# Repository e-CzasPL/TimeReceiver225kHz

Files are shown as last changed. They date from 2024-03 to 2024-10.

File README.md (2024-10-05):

# TimeReceiver225kHz
<html>
<body>
<H1>A simple receiver module for decoding a time frame from a 225kHz transmitter PCSK-225 in Solec Kujawski, Poland</h1>

<H2>Content</H2>
<h3>English</h3>
<ul>
  <li><a href="#en1">Changes</li>
  <li><a href="#en1">What's e-Czas</a></li>
  <li><a href="#en2">What's e-Czas Radio?</a></li>
  <li><a href="#en1">Flash programming guide</a></li>
</ul>
<h3>Polski</h3>
<ul>
<li><a href="#pl0">Zmiany</a></li>
<li><a href="#pl1">Co to jest e-Czas?</a></li>
<li><a href="#pl2">Co to jest e-Czas Radio?</a></li>  
<li><a href="#pl3">Instrukcja programowania procesora</a></li>
</ul>
<h2 id="en0">Changes</h2>
<ul>
  <li><b>2024-06-11:</b> Thanks to Damian Jabłoński, who found an error in the scheme. This caused the processor to operate unstablely. Resistor R2 20k (shown in the current schematic) should be added to fix the error.</li>
   <li><b>2024-06-12:</b> 
   The repository contains corrected versions of the project files in KiCAD. In the KiCAD/1.0/bom folder, you can find the interactive BOM in HTML. In the KiCAD/1.0/production folder, you can find production (Gerber) files for fixed PCB.
   </li>
      <li><b>2024-06-14:</b> The repository contains corrected versions firmware. It doesn't need the resistor R2 (20k). Currently is used internal pull-up resistor.
   </li>

</ul>

<h2 id="en1">What's e-Czas</h2>

<p>Providing the service of reliable and reliable distribution of official time signals valid in the territory of the Republic of Poland and signals of the Polish implementation of the international coordinated universal time UTC (PL), based on the state standard for time measurement units and frequency, with the status (guarantee) of official time and synchronization monitoring service.

<h2 id="en2">What's e-Czas Radio?</h2>

<p>The e-Czas Radio service is used to distribute coded official time signals in the territory of the Republic of Poland using long radio waves. End-user synchronization accuracy: &lt;0.01 s
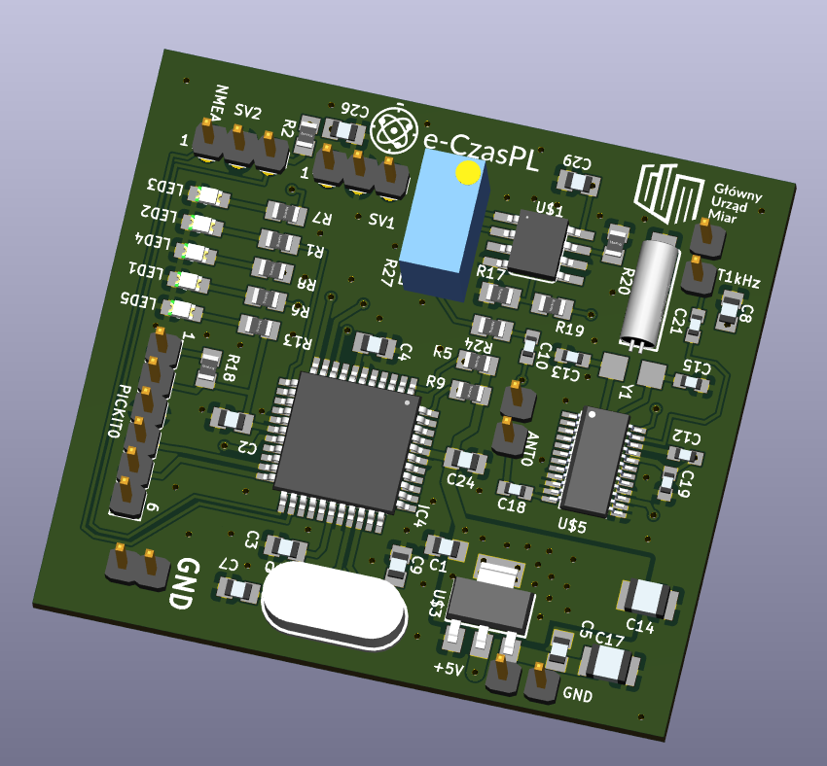
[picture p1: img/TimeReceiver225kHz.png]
Time Receiver 225kHz

<p>As part of the e-CzasPL project, a service was launched for emitting coded digital time signals on long waves, using the 225 kHz carrier wave of the First Polish Radio Program, from a transmitter located in Poland (a technique similar to the DCF77 (Germany), WWVB (USA), JJY (Japan) system, but based on signal phase modulation), which creates a generally available option to synchronize any time-measuring device with the official time in the Republic of Poland using cheap, energy-saving and simple receiving devices. This technique allows many time-measuring devices to be synchronized to the official time in the Republic of Poland with an accuracy of several or a dozen milliseconds. The system is an additional (redundant) source of time information for users located in Poland.
<p>The standard signals are generated using a stable frequency module based on highly stable rubidium frequency standards in the Radio Broadcasting Center (RCN) in Solec Kujawski. Using receiving devices located at the headquarters of the Central Office of Measures in Warsaw, employees of the Time and Frequency Laboratory remotely monitor changes in the frequency of the carrier wave, as well as monitor the accuracy of encoded time signals and compare them with the Official Time Scale in force in the Republic of Poland generated and maintained in the Central Office of Measures.

<p>The technique using digitally coded time signals involves emitted radio waves from RCN Solec Kujawski and the use of dedicated receivers by end users. You can download documentation related to the technical parameters of the transmitted time signal and a description of the process of making a simplified receiver of coded official time signals on the 225 kHz carrier wave of the First Polish Radio Program.
<br><br>
<ul>
<li>In the "/doc" folder, you will find documentation (in Polish) describing how to encode and receive a time frame. 
<li>In the "/Eagle" folder, you can find the design of the receiver in Autodesk Eagle format. 
<li>In the "/KiCAD" folder, you can find the design of the receiver in KiCAD format. 
<li>In the "/Firmware" folder, you can find firmware for the DSPIC33FJ128GP804 processor in HEX format. 

</ul>

<h3>Power</h3>
<p>The best solution is to use a 5V power supply, e.g. USB. Current consumption is approximately 100mA @ 5V.</p>

<h2 id="en3">Flash programming guide</h2>
<p>I use <a href="https://www.microchip.com/en-us/development-tool/PG164150" target=_blank>PICKIT5, which is not much more expensive than the previous ones and can program without a computer, in the "field." The instructions below describe installing the required software in a Windows 11 environment.
<ol>p
<li>Install <a href="https://www.microchip.com/en-us/tools-resources/develop/mplab-x-ide" target=_blank>MPLAB X IDE</a>
<li>When you install MPLAB and connect PICKIT5 to USB, sometimes the system doesn't recognize it properly. Then open "Device Manager" and check the "Ports (COM & LPT) section. It should look like this:<br><br>
In the "Universal Serial Bus devices"<br><br>If no drivers are installed, this will show<br>>
<br>In the "Microchip Tools"<br>
<br>If the last section does not exist, you must update the drivers on your device, which will appear in the "Universal Serial Bus devices" section.
<li>Without the correct driver, the system will show the error "Failed to get Device ID. Please ensure the target device is attached and try the operation again."
<li>Check the 3V3 power supply at the output of the LM1117 stabilizer
<li>Connect the PICKIT5 programmer to the connector on the board. (pins 1 to 5)
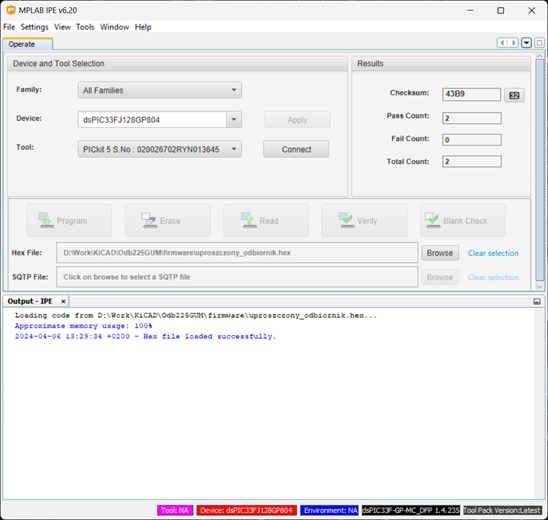
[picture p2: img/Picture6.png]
<li>Run MPLAB IPE - specify the path to the HEX file, processor type<br>
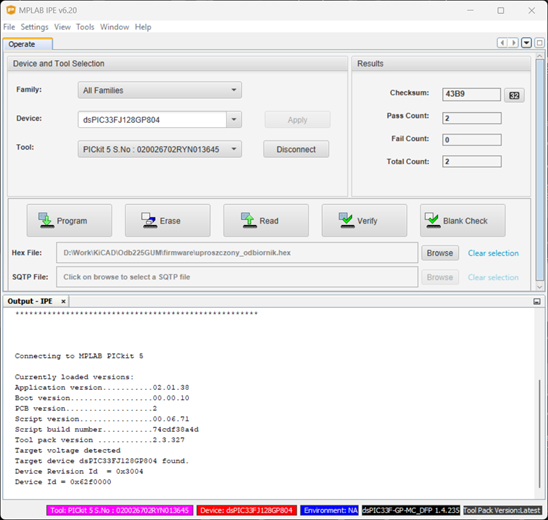
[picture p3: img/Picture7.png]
<li>Click "Connect", the board must be powered<br>
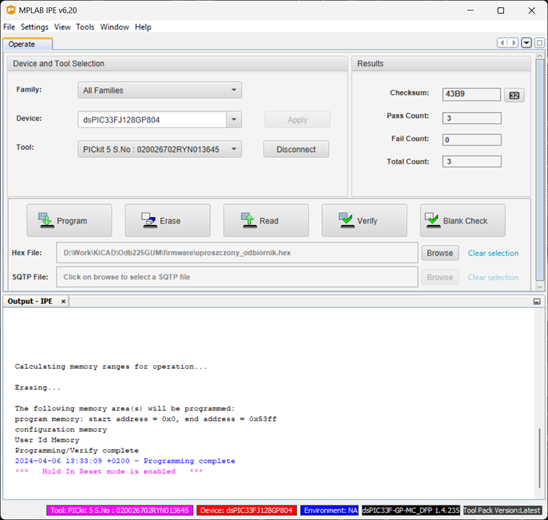
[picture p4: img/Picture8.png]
<li>Program CPU<br>
<li>Turn off the power, disconnect the programmer
</ol>

<h1>Prosty moduł odbiorczy do dekodowania ramek czasu z nadajnika PCSK-225 225kHz w Solcu Kujawskim</h1>

<h2 id="pl0">Zmiany</h2>
<ul>
  <li><b>2024-06-11:</b> Dziękuję Damianowi Jabłońskiemu, który znalazł błąd w schemacie i opracował poprawkę. Błąd skutkował niestabilną pracą procesora. Rozwiązaniem jest dolutowanie rezystora R2 między pinem 3 złącza SV2 a VDD rezystora 20k (R2). Poprawka naniesiona jest na aktualną wersję projektu w KiCAD</li>
   <li><b>2024-06-12:</b> Repozytorium zawiera poprawione pliki projektu. W folderze KiCAD/1.0/bom znajdziesz interaktywny BOM w HTML ułatwiający montaż, w foderze KiCAD/1.0/production są aktualne pliki produkcyjne (Gerber) poprawionego PCB - można je np. wysłać do produkcji (bez rozpakowania).
   </li>
      <li><b>2024-06-14:</b> Repozytorium zawiera poprawiony plik HEX z firmware.  Nie jest konieczne umieszczanie rezystora R2(20k). Obecnie używany jest wewnętrzny rezystor pull-up.
   </li>

</ul>

<h2 id="pl1">Co to jest e-Czas</h2>
Jest tu usługa dystrybucji wiarygodnej i niezawodnej sygnałów czasu urzędowego, obowiązującego na obszarze Rzeczypospolitej Polskiej i sygnałów polskiej realizacji międzynarodowego uniwersalnego czasu koordynowanego UTC(PL), generowanych w oparciu o państwowy wzorzec jednostek miar czasu i częstotliwości, posiadającego status (gwarancję) czasu urzędowego oraz usługi monitorowania synchronizacji.

<h2 id="pl2">Co to jest e-Czas Radio</h2>

<p>Główny Urząd Miar (GUM) uruchomił serwis emitowania kodowanych cyfrowych sygnałów czasu na falach długich, przy wykorzystaniu fali nośnej 225 kHz Programu Pierwszego Polskiego Radia, z nadajnika znajdującego się na terytorium Polski. Jest to technika podobna do systemu DCF77, ale oparta na modulacji fazy sygnału. 
W efekcie powstała ogólnodostępna możliwość zsynchronizowania z czasem urzędowym dowolnego urządzenia odmierzającego czas na obszarze Polski i dużej części Europy przy wykorzystaniu tanich, energooszczędnych i nieskomplikowanych urządzeń odbiorczych. Wykorzystanie tej techniki pozwala na zsynchronizowanie do czasu urzędowego na obszarze RP wielu urządzeń odmierzających czas z dokładnością kilku lub kilkunastu milisekund. System będzie dodatkowym (redundantnym) źródłem informacji o czasie dla użytkowników znajdujących się na terytorium Polski.

<p>Usługa Radia e-Czas służy do dystrybucji kodowanych oficjalnych sygnałów czasu na terytorium Rzeczypospolitej Polskiej za pomocą fal długich radiowych. Dokładność synchronizacji z użytkownikiem końcowym: <0,01 s
Odbiornik czasu 225kHz
<p>W ramach projektu e-CzasPL uruchomiono usługę emisji kodowanych cyfrowych sygnałów czasu na falach długich, wykorzystując falę nośną 225 kHz Pierwszego Programu Polskiego Radia, z nadajnika znajdującego się w Polsce (technika zbliżona do systemu DCF77 (Niemcy), WWVB (USA), JJY (Japonia), ale oparta na modulacji fazy sygnału),  co stwarza ogólnodostępną możliwość synchronizacji dowolnego urządzenia mierzącego czas z czasem urzędowym w Rzeczypospolitej Polskiej za pomocą tanich, energooszczędnych i prostych urządzeń odbiorczych. Technika ta pozwala na synchronizację wielu urządzeń do pomiaru czasu z czasem urzędowym w Rzeczypospolitej Polskiej z dokładnością do kilku lub kilkunastu milisekund. System jest dodatkowym (redundantnym) źródłem informacji o czasie dla użytkowników znajdujących się na terenie Polski.
<p>Sygnały standardowe generowane są w oparciu o moduł częstotliwości stabilnej oparty na wysoce stabilnych wzorcach częstotliwości rubidowych w Radiostacji Nadawczej (RCN) w Solcu Kujawskim. Pracownicy Laboratorium Czasu i Częstotliwości zdalnie monitorują zmiany częstotliwości częstotliwości fali nośnej, a także monitorują dokładność kodowanych sygnałów czasowych i porównują je z obowiązującą w Rzeczypospolitej Polskiej Oficjalną Skalą Czasu generowaną i utrzymywaną w Głównym Urzędzie Miar.

<p>Technika wykorzystująca cyfrowo kodowane sygnały czasu polega na emisji fal radiowych z RCN Solec Kujawski oraz wykorzystaniu dedykowanych odbiorników przez użytkowników końcowych. Można pobrać dokumentację związaną z parametrami technicznymi nadawanego sygnału czasu oraz opis procesu wykonania uproszczonego odbiornika kodowanych oficjalnych sygnałów czasu na fali nośnej 225kHz Pierwszego Programu Polskiego Radia (PCSK-225).
<br><br>
<ul>
<li>W folderze "/doc" znajdziesz dokumentację opisującą sposób kodowania i odbierania ram czasowych. 
<li>W folderze "/Eagle" znajduje się projekt odbiornika w formacie Autodesk Eagle. 
<li>W folderze "/KiCAD" znajduje się projekt odbiornika w formacie KiCAD. 
<li>W folderze "/Firmware" można znaleźć oprogramowanie układowe dla DSPIC33FJ128GP804 procesora w formacie HEX. 

</ul>
<h3>Zasilanie</h3>
<p>Najlepszym rozwiązaniem jest użycie zasilania 5V np. USB. Pobór prądu wynosi ok 100mA przy 5V.</p>

<h2 id="pl3">Instrukcja programowania procesora</h2>
<p>Ja używam <a href="https://www.microchip.com/en-us/development-tool/PG164150" target=_blank>PICKIT5, niewiele droższy od poprzednich a mający dodatkowo możliwość programowania bez komputera, w "polu". Poniżej opisuje instalację wymaganego oprogramowania w środowisku Windows 11.
<ol>
<li>Zainstaluj <a href="https://www.microchip.com/en-us/tools-resources/develop/mplab-x-ide" target=_blank>MPLAB X IDE</a>
<li>Po zainstalowaniu MPLAB i podłaczeniu PICKIT5 do USB czasami system nie rozpoznaje go prawidłowo. Wtedy otwórz "Device Manager" i sprawdź sekcję "Ports (COM & LPT). Powinna wyglądać tak:<br><br>
W sekcji "Universal Serial Bus devices"<br><br>Jeżeli nie są zainstalowane sterowniki, pokaże się to<br>>
<br>W sekcji "Microchip Tools"<br>
<br>Jeżeli ostatnia sekcja nie istnieje należy zaktualizować sterowniki w urządzeniu które pojawi się w sekcji "Universal Serial Bus devices".
<li>Bez prawidłowego sterownika, system pokaże błąd "Failed to get Device ID. Please make sure the target device is attached and try the operation again."
<li> sprawdzić zasilanie 3V3 na wyjściu stabilizatora LM1117
<li>Podłączyć programator PICKIT5 do złącza na płytce. (piny od 1 do 5)
<li>Uruchomić program MPLAB IPE - podać ścieżgę do pliku HEX, typ procesora<br>
<li>Kliknąć "Connect", płytka musi być zasilana<br>
<li>Zaprogramować procesor<br>
<li>Wyłączyć zasilanie, odłączyć programator
</ol>

<h2>Projekty połączone</h2>
<ol>
<li><a href="https://github.com/J-K-Kowalski/PCSK225-Antenna" target="_blank">Antena aktywna na tranzystorze FET</a></li>
<li><a href="https://github.com/J-K-Kowalski/PCSK225_RECV_USB" target="_blank">Odbiornik z interfejsem USB</a></li>
<li><a href="https://github.com/sp5wwp/e-Czas" target="_blank">SP5WWP - Dekoder e-Czas</a></li>
<li><a href="https://github.com/sp6hfe/e-CzasPL" target="_blank">e-CzasPL Radio reference C++ data decoder by SP6HFE</a></li>
</ol>

<p>Jurek K. Kowalski
<p>
<table border=0 cellpadding=0 cellspacing=0 width="100%"><tr>
<td align=left>
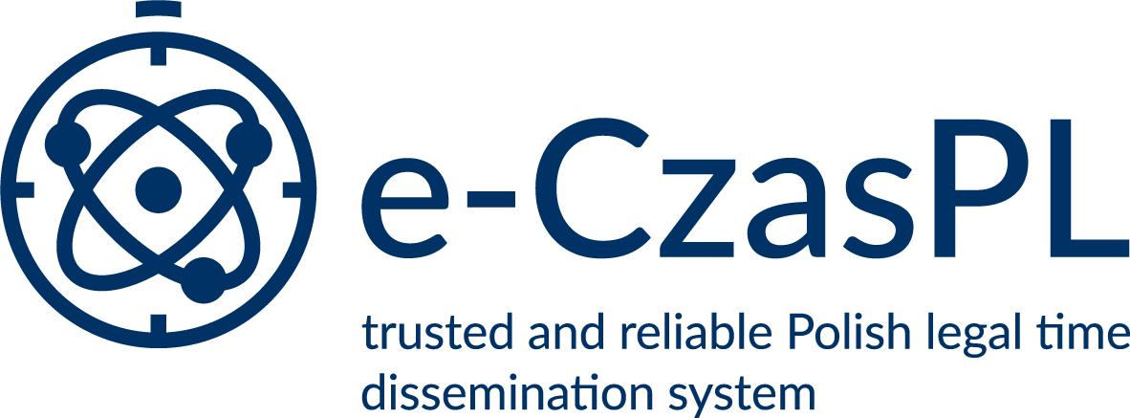
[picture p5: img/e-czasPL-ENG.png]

</td>
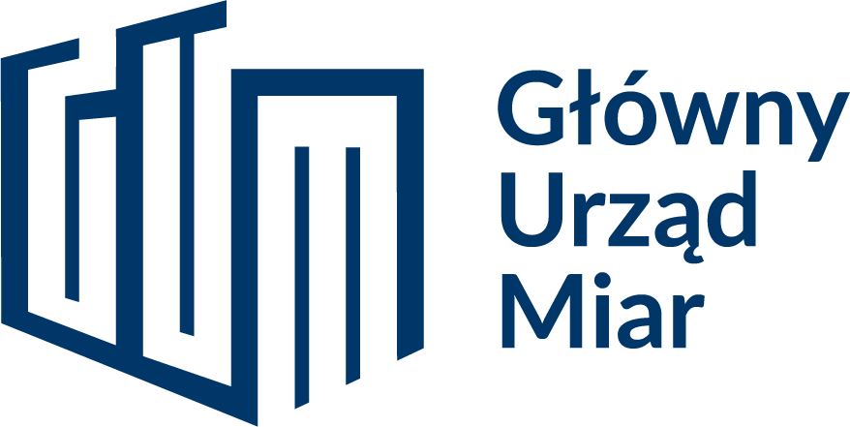
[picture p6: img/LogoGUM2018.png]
<td align=right>
</td>
</tr>
</table>
</body>
</html>

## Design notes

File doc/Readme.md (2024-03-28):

Distribution of Polish official time on long radio waves, using the 225 kHz carrier wave of the First Polish Radio Program - frame structure, transmitted data and their purpose.

Wersja polska
1. e-CzasPL-Opis-projektu-przykladowego-modulu-odbiorczego-e-Czas-Radio.pdf - dokumentacja do prostego odbiornika sygnałów czasu z nadajnika PCSK-225
2. e-CzasPL-Opis-ramki-czasu-e-Czas-Radio.pdf - opis ramki czasu w nadajniki PCSK-225

English version
1. Simple Time Receiver for PCSK-225.pdf - documentation of Simple Time Receiver.
2. PCSK-225 - Distribution of official time on long waves.pdf - description of time frame for PCSK-225 sender.

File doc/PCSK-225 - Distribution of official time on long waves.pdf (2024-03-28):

Distribution of official time Frame structure, transmitted data, and purpose

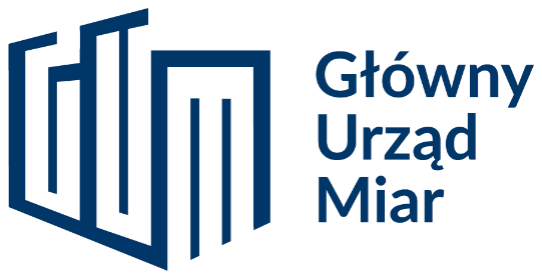
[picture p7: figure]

Distribution of official time on long waves, using.

## the 225 kHz carrier wave of the First Polish Radio Program

## frame structure, transmitted data, and its purpose

v. 1.0

Frame structure, transmitted data, and purpose

## Contents

Frame structure, transmitted data, and purpose

### 1. Diagram of the system:

The system's transmission is organized in time slots of 3 seconds. Messages are sent at a bit rate of 50 bps. In each time slot, the transmission starts at the beginning of the second. After transmitting each command, the system turns off the carrier phase modulation for the next full second. The traffic generated by the Radio Broadcasting Center (RCN) takes place in 20 time slots (from 0 to 19). They constitute a frame transported for 1 minute (minute frame).

Slot number | Elapsed time since the beginning of the broadcast [s] | Destiny
0 | 0 | Time Message 0
1 | 3 | Message 1
2 | 6 | Message 2
3 | 9 | Message 3
⋮ | ⋮ | ⋮
18 | 54 | Message 18
19 | 57 | Message 19

Fig. 1 Minute frame of the system.

Frame structure, transmitted data, and purpose

### 2. Structure of the official time frame:

A time frame consists of 12 bytes, i.e., 96 bits sent at a bit rate of 50 bits/s. This means that it takes 1.92 seconds to send a full-time frame.

BYTE
NO.

1

### 16 b → SYNCHRONIZATION STRING

2

3 8 b → TIMEFRAME START MARKER

4

### 3 b → TIME OF ENTRY TO RECEIVER

### 30 b → OFFICIAL TIME

5

6

7

8

### 2 b → LOCAL TIME

### 1 b → LEAP SECOND PREVIEW

### 1 b → LEAP SECOND SIGN

### 1 b → CHANGING LOCAL TIME

### 2 b → LONG-WAVE TRANSMITTER STATUS

9

10 24 b → REED-SOLOMON CORRECTION CODES

11

12 8 b → CRC-8 CHECKSUM

Fig. 2 Block structure of a time message.

Frame structure, transmitted data, and purpose

In addition, 2 B (0x680C – 0b0110 0b1000 0b0000 0b1100) are transmitted before each frame, which is the start sequence. They are not part of the time message.
The following is the bitwise frame format:

Fig. 3 Bit structure of a time message.
Purpose of individual bits:
- 0x55H | - constant synchronization pattern;
- 0x60H | - a permanent template signaling the beginning of the official time frame distributed as part of "e-CzasPL";
- 0x5H (0b101) - bits specifying the moment of entering the sent time into the
| receiver registers – delayed by 0.5 s (25b × 0.02 s = 0.50 s) about the moment of starting to transmit the frame;
- S0 ÷ S29 | - bits indicating the number of three-second periods counted from 1 January 2000 (3 × (S0 ÷ S29) = number of seconds counted from 1 January 2000;
- TZ0 ÷ TZ1 | - bits specifying the local time; to calculate the local time, add to the time received from the time frame the appropriate offset determined by bits TZ0 and TZ1 (according to the table below);
TZ0 | TZ1 | Local Time
0 | 0 | 0
1 | 0 | +1 hour
0 | 1 | +2 hours
1 | 1 | +3 hours
- LS | - bit indicating that a leap second announcement/no announcement is being broadcast: 0 – no leap second announcement, 1 – announcement of the introduction of a leap second; A leap second can be introduced at the beginning of the quarter: Variant I – 1 January or 1 July, Variant II – 1 April or 1 October
0 | 1 | 0 | 1 | 0 | 1 | 0 | 1 | 0 | 1 | 0 | 1 | 0 | 1 | 0 | 1
0 | 1 | 1 | 0 | 0 | 0 | 0 | 0 | 1 | 0 | 1 | S0 | S1 | S2 | S3 | S4
S5 | S6 | S7 | S8 | S9 | S10 | S11 | S12 | S13 | S14 | S15 | S16 | S17 | S18 | S19 | S20
S21 | S22 | S23 | S24 | S25 | S26 | S27 | S28 | S29 | TZ0 | TZ1 | LS | LSS | TZC | SK0 | SK1
Reed-Solomon ECC byte 0 | Reed-Solomon ECC byte 1
Reed-Solomon ECC byte 2 | CRC-8

Frame structure, transmitted data, and purpose

at 0:00 UTC; the leap second announcement should be broadcast in the period from a few days to a maximum of 1 week before the planned moment of introduction of the leap second;
- LSS | - the bit specifying the leap second sign:
| 0 – adding a second,
| 1 – subtract a second;
- TZC | - a bit informing that following Sunday at 1:00 UTC, there will be a
| change of local time to summer or winter/ordinary time. By default,
| daylight saving time changes occur on the last Sunday in March
| (Daylight Saving Time) and the last Sunday in October (Daylight
| Saving Time/Daylight Saving Time); the announcement of the
| upcoming time change should be broadcast up to a few days in
| advance (up to a maximum of 6 days) before the planned local
| time change;
- SK0 ÷ SK1 | - bits determining the state of the transmitter in Solec Kujawski
| according to the table below:
SK0 | SK1 | Condition of the transmitter PCSK-225 in Solec Kujawski
0 | 0 | Normal Operation
1 | 0 | Planned shutdown for one day
0 | 1 | Planned shutdown for a week
1 | 1 | Planned shutdown for more than a week

At the end of the time frame, 3 Reed-Solomon correction bytes are sent to allow correction of up to 24 bits of the frame. Bits to be corrected

### 3. Reed-Solomon Correction Coding:

The implemented Reed-Solomon algorithm can cover 36 bits. The correction covers bits S0 ÷ SK0 (marked in green in Fig. 1).

NOTE
The last bit of the SK1 usage data is not corrected (see Fig. 1). NOTE

The correction block consists of 24 redundant bits (bytes 9 ÷ 11).

### 4. Checksum and scrambling:

The last free byte is assigned to the CRC-8 checksum.

Frame structure, transmitted data, and purpose

NOTE
In the previous version of the time frame, 4 bytes of the R-S correction algorithm were predicted. (change after 04.09).

NOTE

The checksum is calculated from whole bytes 4 ÷ 8 (bits 25 ÷ 64) After scrambling, in the scramble process, the data is XOR with the string 0x0A47554D2B, which in the ASCII code corresponds to \NGUM+. Descrambling is accomplished by repeating this operation.

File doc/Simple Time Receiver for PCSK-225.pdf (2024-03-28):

Distribution of official time Description of an example receiver module

## Str. 1


## Distribution of official time on long waves, using the 225 kHz carrier wave of the First Polish Radio Program

## Description of the design of an exemplary receiver module for encrypted official time signals

v. 1.0

Description of an example receiver module

### 1 Table of contents

Description of an example receiver module

The Central Office of Measures (GUM) has launched a service for broadcasting encoded digital time signals on long waves, using the 225 kHz carrier wave of the First Polish Radio Program, from a transmitter located in the territory of Polish. It is a technique similar to the DCF77 system but based on signal phase modulation. As a result, it is possible to synchronize timekeeping devices in Poland and a large part of Europe with the official time using cheap, energy-efficient, and uncomplicated receiving devices. This technique makes it possible to synchronize many timekeeping devices with an accuracy of a few or several milliseconds to the official time in the territory of the Republic of Poland. The system will be an additional (redundant) source of time information for users located in Polish.

Using digitally coded time signals involves adding an appropriate device (modulator) to the infrastructure for emitting radio waves at RCN Solec Kujawski (PCSK-225) and implementing receivers. The receiver performs its tasks automatically (i.e., determines the official time based on the emitted time signals) after correctly receiving the received signal.

2 Technical requirements of the receiver, time signal parameters.

The receiver will be adapted to receive signals with the following characteristics:

1) frequency with a nominal value of 225 kHz, transmitted from the transmitter of the Radio Broadcasting Centre (PCSK-225) in Solec Kujawski, with amplitude modulation of the acoustic radio signal and a dynamic carrier wave level control system;
2) dynamically variable carrier wave level (in the range from 0 dB to approx. -6.4 dB relative to the maximum carrier wave level) depending on the depth of acoustic signal modulation (AM modulation) and the set operating mode;
3) possible periodic shutdown of the 225 kHz long-wave transmitter for the duration of inspections (on average once a year for approx. 20 hours) and maintenance (on average once every five years for approx. two weeks) and short-term interruptions in signal emission (typically less than 2 hours) for other reasons;
4) implemented PSK (Phase Shift Keying) modulation of the NRZ (Non-Return-To-Zero) type, binary signal with smooth linear phase changes of the carrier wave – with the possibility of changing (within a fixed limited range) selected coding parameters: the value of the depth of the (additional) phase shift of the carrier wave when transitioning to a new state (01 or 10), the time it takes to complete the transition to a new state (01 or 10), transmission speed;
5) possibility of periodic coexistence of additional frames with dynamically changed transmission parameters, length and content of the message – PSK modulation type NRZ – possibility of changed transmission speed, depth of (additional) phase shift of the carrier wave, time of transition to the new state, change of error correction code, frame length;
6) start of transmitting a group of frames: at every full minute and subsequent frames (start of sending) at intervals of 3 s, possible deliberate short-term interruptions in the

Description of an example receiver module

transmission of frames constituting multiples of the interval of 3 s;
7) no collision of frames transmitted for the needs of different systems (broadcasting schedules may overlap in time but do not coincide);
8) the transmission of each frame takes less than 3 seconds;
9) during the transition to the new state, the maximum deviation of the carrier wave frequency does not exceed ± 100 Hz;
10) adopted basic modulation format of encoded official time signals: PSK modulation type NRZ, transmission speed 50 bit/s, depth of (additional) phase shift of the carrier wave
- 36° ± 3.6° (10 % of the carrier wave period), frame length – 14 bytes, synchronization bytes, some transmission parameters may be slightly modified over time, e.g. the depth of the (additional) phase shift of the carrier wave, or the time of the transition to a new state (01 or 10);
11) the level (surface wave field strength) of the received 225 kHz signal from the longwave transmitter in the PCSK-225 in Solec Kujawski in most of the Polish region is estimated to be above 78 dB (μV/m) – there are areas where the signal level decreases locally to the level of about 70 dB (μV/m).

### 3 Receiver concept

The receiver can be divided into two functional blocks;
- Frontend RF - Radio Frequency Receiver
- DSP demodulator

The RF front end is based on the SI4735 integrated circuit, whose block diagram is shown in Figure 1.

Description of an example receiver module

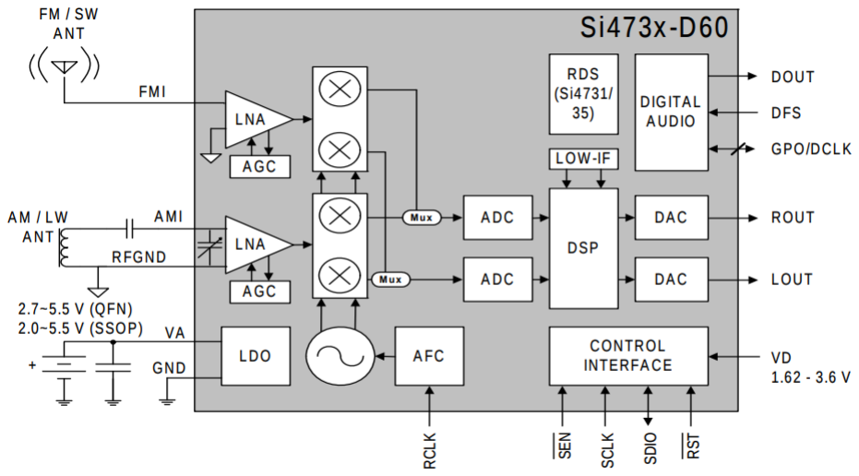
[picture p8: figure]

Figure 1. The RF frontend of the sample receiver module.

The device allows to receive long waves in the range of 153-279 kHz; thanks to the use of a DSP processor, it is possible to use the device in a non-standard way and use it as an SSB receiver (in this case, USB) working with BFO at a frequency of 224 kHz, which results in the reproduction of the transmitter's carrier wave output transferred to the acoustic band - in this case 1 kHz. In addition, the system provides automatic gain adjustment. The frontend layout is controlled by a frequency of 32.768 kHz obtained from a quartz generator.

The signal received this way is sent for further processing in the dsPIC33 signal processor. After initial filtering through a bandpass filter with a width of 200 Hz. Demodulator concept

During processing, the information from the PSK modulation signal is recovered in the DSP, and then, after passing through the packer, the frame classification takes place. When a keyword is detected, 0x60 subsequent bytes are written to the buffer, and R-S correction is performed. Then, the correctness of the received data is verified (the so-called "sanity checks")
- whether there has been a "time shift" or a "jump into the future" more significant than it would result from predictions based on the observation of the local RTC.

Measurement of time intervals between successive received frames will allow determining the frequency difference and carrying out systematic correction of the time scale created in the receiver.

After verifying the received data, the processor controls the 1PPS generator.

Description of an example receiver module

### 4 DSP Block Description

The DSP block is based on the dsPIC33FJ128GP804 processor. The processor was chosen due to design requirements (according to the order, the platform should be expandable in the future). The signal demodulation process takes about 10% of the processor's time, leaving a large reserve of computing power for future applications.

The processor's analog-to-digital converter input is supplied with an audio signal from the tuner's output. This type of solution allows you to separate the radio part from the digital part. In very difficult reception conditions (e.g., on deep-sea vessels), a professional radio communication receiver can also be used, and the audio signal can be delivered directly to the DSP.

The process of demodulating time frames takes several steps. After filtering the signal through a bandpass filter with a center frequency of 1 kHz and a bandwidth of 200 Hz, the signal is fed to a software-implemented Costas loop, which allows for the detection of changes in the signal's phase. The data stream is then passed to the bit-slicer, and the resulting bitstream feeds the packetizer, which parses the synchronization bits and the keyword.

When a data frame is received, correction codes are calculated, and frame consistency tests are performed.

In addition, the DSP will act as the RTC clock.

### 5 Data Frame Description

The following frame applies to the system.

### 5.1 Frame format

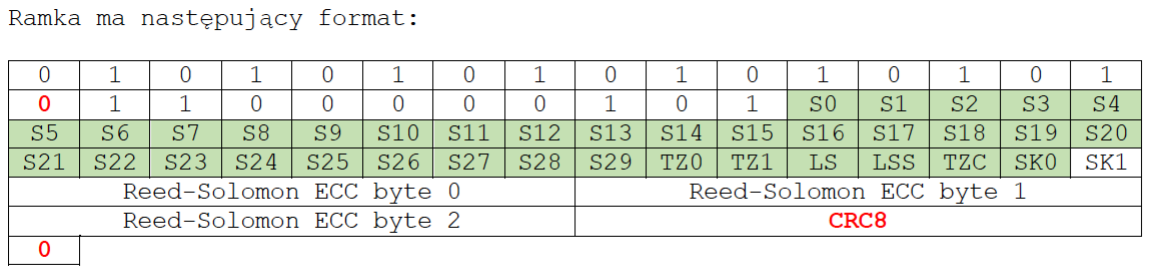
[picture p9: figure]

Table 1. The format of the official time frame.

It consists of 12 bytes, i.e., 96 bits sent at a bit rate of 50bit/s. This means that it takes 1.92s to send a total time frame. Frames are sent by the transmitter in Solec Kujawski in time slots

Description of an example receiver module

every 3 seconds. This will give the receiver ample time to demodulate and decode the sent frame. After two synchronization bytes (55H), the 60H beginning marker is sent, which differs by 7 bits from the marker used by Enea's system to control lighting. In this way, both systems will not interfere with each other (Enea's receivers, after detecting another tag, ignore the entire frame. Then three "1-0-1" (5H) bits are sent, of which bit 0 specifies the 'conventional' moment of entering the sent time into the receiver registers – delayed by 0.5s (25 bits x 0.02s = 0.50s) about the moment of starting to transmit the frame. S0 ÷ S29 Bits (30 bits) specifying the number of three-second seconds counted from 1 January 2000, i.e. 3 x (S0 ÷ S29) = number of seconds counted from 1 January 2000.

TZ0 TZ1 The bits specifying the local time are shown in the table below:

TZ0 | TZ1 | Local Time
0 | 0 | 0
1 | 0 | +1 hour
0 | 1 | +2 hours
1 | 1 | +3 hours

Table 2. Time bits.

### 5.2 Correction Codes

At the end of the time frame, 3 Reed-Solomon correction bytes are sent to allow correction of up to 24 bits of the frame.

The frame implements R-S encoding in the version:
4b - size of the codeword,
3b - correction strength.

What gives:
Data block: 9 words = > 36 bits,
Correction block: 6 words = > 24 bits.
The bits (S0 ÷ SK0) <= 36 bits are corrected - marked in the table. The last bit of SK1 usage data has not been corrected.
The last free byte is assigned to the CRC-8 checksum.

### 5.3 Scrambling

The usage data is XOR with the binary string 0A 47 55 4D 2B which corresponds to: "\NGUM+"

### 5.4 NMEA RMC Frame Format

The receiver of the e-CzasPL system is designed to provide information about the official time.

Description of an example receiver module

The NMEA protocol was used to facilitate the transition from GNSS to e-CzasPL, which simulates the behavior of a GNSS receiver. The RMC (Recommended Minimum Specific GNSS Data) sentence was used for time synchronization. For obvious reasons, the receiver does not know its geographical location. The static coordinates of the Time and Frequency Laboratory of the Central Office of Measures (52.24183 N, 21.00084 E) are transmitted in the frame to maintain compatibility with GNSS receivers.

An example of the GPRMC sentence is presented below:

$GPRMC,120000,A,5214.5098,N,02100.0504,E,0.00,000.021123,,E,A*CCCC

NAME | EXAMPLE | DESCRIPTION
Operative part ID | $GPRMC | NMEA Heading of RMC Operative Part
UTC | 120000 | hhmmss
Status | A | A – valid data, V – invalid data
latitude | 5214.5098 | ddmm.mmmm – GUM laboratory position
N/S | N | N – north latitude, S – south latitude
longitude | 02100.0504 | dddmm.mmmm - GUM laboratory item
E/W | E | E – east longitude, W – west longitude
velocity | 0.00 | Speed in knots – in this case, static position
course | 000.0 | Course in degrees - in this case, a static position
date | 021123 | ddmmyy
Magnetic deflection | | In this case, the static position
E/W | E | Direction of deviation mag. - Static position
Mode | A | A = Autonomous
checksum | *cccc
<CR><LF> | | End marker of the sentence
Table 3. An example of a GPRMC sentence.

The beginning of the NMEA sentence (the $ sign) is sent at the start of the second place in the sentence.

It is possible to modify the receiver firmware so that any geographical position can be entered during the receiver configuration.

5.5 5.5 DSP Firmware

The receiver software was written in C (central part) and Assembler (part of the demodulator) and was compiled with MPLAB XC16 PRO compiler version 2.10 on the Linux platform.

This documentation is accompanied by a HEX file that is ready to be uploaded to the DSP. One of the programmers must upload the software to the processor: PICKIT3, PICKIT4, PICKIT5, ICD-3, or ICD-4. The software can be uploaded to a microcontroller soldered to the PCB using the PICKIT connector.

Description of an example receiver module

### 6 Simple e-CzasPL Time Receiver

The e-CzasPL system's simple receiver has been designed to be built with a minimal set of tools. Manual assembly is possible, and only basic knowledge of working with SMD components is required. A properly built circuit does not require tuning or configuration. The device works immediately after connecting the power supply and is ready to receive the time signal.

The e-CzasPL signal receiver has been designed as an independent module that can be used as an official time standard on your devices. An exemplary receiver design can be used for one's needs in projects where information about the time related to the official time in force in the territory of the Republic of Poland is used.

The receiver provides time data in the form of NMEA RMC sentences, a 1 PPS signal, and a raw, unprocessed data frame for processing in an external system.

The receiver has a built-in RTC clock, which is designed to keep time for 24 hours from the last correctly received frame. After 24 hours, the "FIX" signal about time synchronization is extinguished. The system will still provide both time information (NMEA RMC sentence) and a 1PPS signal, but there is no guarantee that the required compliance with the official time will be maintained.

### 6.1 SV1 Diagnostic Connector

Similar to the basic version of the receiver, the SV1 connector has a UART port for the microcontroller operating at CMOS 3.3V levels—transmission parameters 115200 bps 8N1. Diagnostic information, including raw hexadecimal frames, is sent to the connector.

### 6.2 NMEA connector

Similarly to the basic version of the receiver, the SV2 connector is exposed to NMEA-compatible data carrying time information. The NMEA format was chosen for compatibility with GNSS-compatible devices. For a description of the NMEA frame, see Section 5.4. The connector operates at 3.3V CMOS levels

### 6.3 Antenna Connector

The antenna connector of the simplified receiver should be supplied with an RF signal from a ferrite antenna or an external antenna. The input circuit of the RF frontend is very tolerant and resistant to impedance mismatch.

Description of an example receiver module

### 6.4 Signaling the Operating Status of the Receiver

On the PCB of the Simple Receiver, 5 SMD LEDs indicate the receiver's operating status.
- LED1 – lit after correct receipt of the data frame, recalculated correction codes, and confirmed data correctness. The rising edge informs about the start of the second (transmitted in the data frame),
- LED2 – DCD – signaling of recognition of the beginning of the data frame (after the keyword is detected) – remains lit until the end of the frame transmission,
- LED3 – Informs about receiving the correct time and entering it into the RTC, if it is not possible to update the RTC from the radio transmission, the LED is turned off after 24 hours,
- LED4 – 1PPS 1PPS signal synchronized with the received time signal,
- LED5 – signaling the presence of a power supply to the system.

Remark! The 1PPS signal is valid (according to the official time) only when LED3 is lit.

7 7 Simplified Receiver Executive Documentation

The system was designed using Autodesk Eagle software. Schematic, mosaic, and GERBER files for PCB circuits are attached to this documentation. The circuit should be assembled, paying attention to the arrangement of electronic components, the integrated circuits' orientation, and the LEDs' polarity. The PCB is designed to facilitate the manual assembly of components.

It is not necessary to use a stencil to apply the solder paste. With some practice, installation can be done with tweezers and a classic soldering iron. A microscope or magnifying glass can be very helpful.

The time receiver has been designed so people without DSP programming or digital signal processing techniques can assemble and run it.

Figure 11 shows the schematic diagram of the time receiver.

Description of an example receiver module

7.1 7.1 Schematic diagram of the Time Receiver

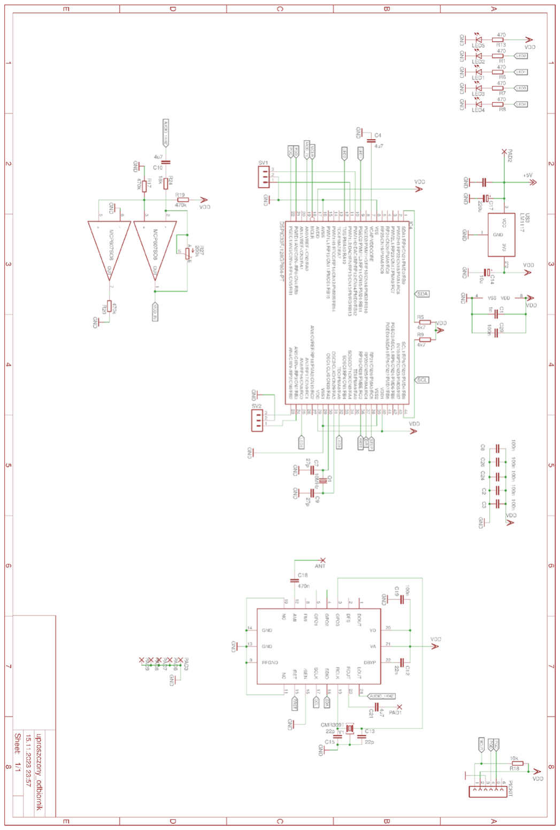
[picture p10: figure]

Figure 2. Schematic diagram of a time receiver.

Description of an example receiver module

### 7.2 Time Receiver PCB – Components Page

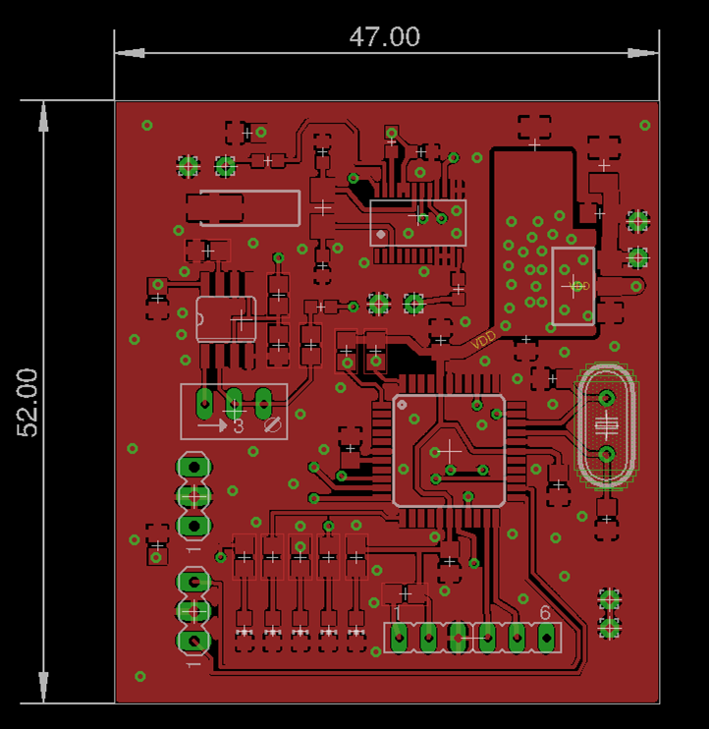
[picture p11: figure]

Figure 3. Time Receiver PCB – Components Page.

Description of an example receiver module

### 7.3 Time Receiver PCB – Print Side

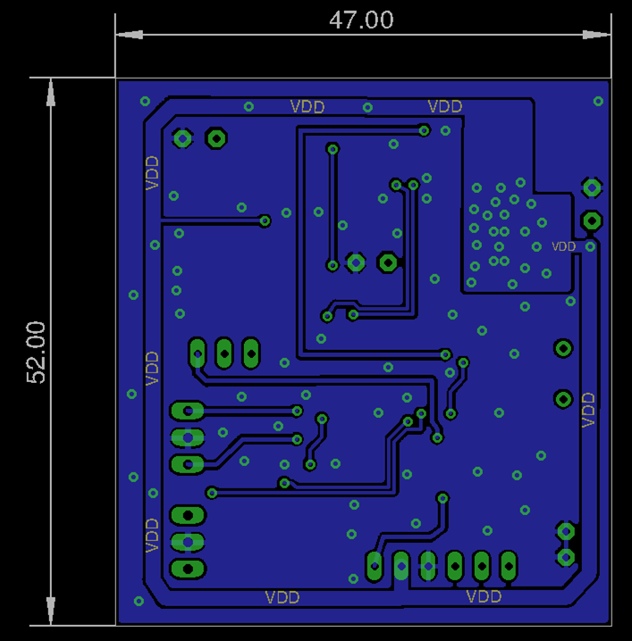
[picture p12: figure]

Figure 4. Simplified Receiver PCB – Print Side.

### 7.4 Time Receiver Bill of Materials (BOM)

Element | value | Device | Case
C1 | 1n | C-EUC0805K | C0805K
C2 | 100N | C-EUC0805K | C0805K
C3 | 100N | C-EUC0805K | C0805K
C4 | 4u7 | C-EUC0805K | C0805K
C5 | 100N | C-EUC0805K | C0805K
C7 | 27p | C-EUC0805K | C0805K
C8 | 100N | C-EUC0805K | C0805K

Description of an example receiver module

C9 | 27p | C-EUC0805K | C0805K
C10 | 4u7 | C-EUC0603K | C0603K
C12 | 22n | C-EUC0603K | C0603K
C13 | 22p | C-EUC0603K | C0603K
C14 | 10u | CPOL-EUSMCB | SMC_B
C15 | 22p | C-EUC0603K | C0603K
C17 | 220u | CPOL-EUSMCB | SMC_B
C18 | 470N | C-EUC0603K | C0603K
C19 | 100N | C-EUC0603K | C0603K
C21 | 4u7 | C-EUC0603K | C0603K
C24 | 100N | C-EUC0805K | C0805K
C26 | 100N | C-EUC0805K | C0805K
C29 | 100N | C-EUC0805K | C0805K
IC4 | DSPIC33FJ128GP804-PT | DSPIC33FJ128M | C804-PT TQFP44
LED1 | LED | LEDCHIP-LED0 | 805 CHIP-LED0805
LED2 | LED | LEDCHIP-LED0 | synchronize any timekeeping device in Polish and a large part of Europe with the official time using cheap, energy-efficient,
LED3 | LED | LEDCHIP-LED0 | 805 CHIP-LED0805
LED4 | LED | LEDCHIP-LED0 | 805 CHIP-LED0805
LED5 | LED | LEDCHIP-LED0 | synchronize any timekeeping device in Polish and a large part of Europe with the official time using cheap, energy-efficient,
PICKIT | pin connector 2.54x6 | FE06-1 | FE06
Q1 | Quartz 10MHz | CRYSTALHC49U | HC49U-V
R1 | 470 | R-EU_R0805 | R0805
R5 | 4k7 | R-EU_R0805 | R0805
R6 | 470 | R-EU_R0805 | R0805
R7 | 470 | R-EU_R0805 | R0805
R8 | 470 | R-EU_R0805 | R0805
R9 | 4k7 | R-EU_R0805 | R0805
R13 | 470 | R-EU_R0805 | R0805
R17 | 470k | R-EU_M0805 | M0805
R18 | 10k | R-EU_R0805 | R0805

Description of an example receiver module

R19 | 470k | R-EU_M0805 | M0805
R20 | 470k | R-EU_M0805 | M0805
R24 | 18k | R-EU_M0805 | M0805
R27 | 200k | TRIM_EU-RJ9W | RJ9W
SV1 | 2.54 mmx3 pin connector | MA03-1 | MA03-1
SV2 | 2.54 mmx3 pin connector | MA03-1 | MA03-1
U$1 | MCP607SO8 | MCP607SO8 | SOIC8
U$3 | LM1117 | LM1117 | SOT223-3
U$5 | SI4735-D60 | SI4735-D60 | SSOP24
Y1 | Quartz 32.768 kHz | CMR309T | CMR309T
Table 2

### 7.5 Time Receiver Firmware

The Simplified Receiver works based on the same firmware as the basic version. Similarly to the basic version, the software should be uploaded to the DSP using one of the programmers: PICKIT3, PICKIT4, PICKIT5, ICD-3, or ICD-4. The software should be uploaded to the processor after it has been placed on the PCB by connecting the programmer to the PICKIT connector.

When the device starts, the software automatically recognizes whether it is working in the basic or simplified version of the receiver and takes appropriate action.

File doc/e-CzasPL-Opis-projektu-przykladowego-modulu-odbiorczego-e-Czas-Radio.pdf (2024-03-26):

Dystrybucja czasu urzędowego Opis przykładowego modułu odbiorczego

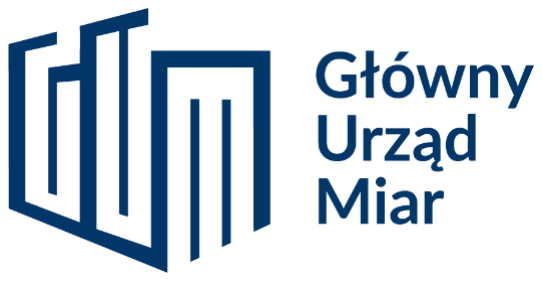
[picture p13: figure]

## Dystrybucja czasu urzędowego na falach długich, przy wykorzystaniu fali nośnej 225 kHz Programu Pierwszego Polskiego Radia

## opis projektu przykładowego modułu odbiorczego kodowanych sygnałów czasu urzędowego

v. 1.0

str. 1

Opis przykładowego modułu odbiorczego

### 1 Spis treści

2 Wymagania techniczne odbiornika, parametry sygnału czasu. | 3
3 Koncepcja wykonania odbiornika | 4
4 Opis bloku DSP | 6
5 Opis ramki danych | 6
5.1 Format ramki | 6
5.2 Kody korekcyjne | 7
5.3 Scrambling | 7
5.4 Format ramki NMEA RMC | 7
5.5 Oprogramowanie wbudowane DSP | 8
6 Uproszczony Odbiornik sygnału e-CzasPL | 9
6.1 Złącze diagnostyczne SV1 | 9
6.2 Złącze NMEA | 9
6.3 Złącze Antenowe | 9
6.4 Sygnalizacja stanu pracy Uproszczonego Odbiornika | 9
7 Dokumentacja Wykonawcza Uproszczonego Odbiornika | 10
7.1 Schemat ideowy Uproszczonego Odbiornika | 11
7.2 Płytka PCB Uproszczonego Odbiornika – strona elementów | 12
7.3 Płytka PCB Uproszczonego Odbiornika – strona druku | 13
7.4 Zestawienie elementów Uproszczonego Odbiornika (BOM) | 14
7.5 Oprogramowanie układowe Uproszczonego Odbiornika | 15

Opis przykładowego modułu odbiorczego

Główny Urząd Miar (GUM) uruchomił serwis emitowania kodowanych cyfrowych sygnałów czasu na falach długich, przy wykorzystaniu fali nośnej 225 kHz Programu Pierwszego Polskiego Radia, z nadajnika znajdującego się na terytorium Polski. Jest to technika podobna do systemu DCF77, ale oparta na modulacji fazy sygnału. W efekcie powstała ogólnodostępna możliwość zsynchronizowania z czasem urzędowym dowolnego urządzenia odmierzającego czas na obszarze Polski i dużej części Europy przy wykorzystaniu tanich, energooszczędnych i nieskomplikowanych urządzeń odbiorczych. Wykorzystanie tej techniki pozwala na zsynchronizowanie do czasu urzędowego na obszarze RP wielu urządzeń odmierzających czas z dokładnością kilku lub kilkunastu milisekund. System będzie dodatkowym (redundantnym) źródłem informacji o czasie dla użytkowników znajdujących się na terytorium Polski.

Technika wykorzystująca cyfrowe kodowane sygnały czasu polega na dodaniu odpowiedniego Urządzenia (modulatora) do infrastruktury emitowania fal radiowych w RCN Solec Kujawski oraz implementacji odbiorników. Odbiornik realizuje swoje zadania automatycznie (tj. wyznacza czas urzędowy na podstawie emitowanych sygnałów czasu) po poprawnym odbiorze odebranego sygnału.

2 Wymagania techniczne odbiornika, parametry sygnału czasu.

Odbiornik będzie przystosowany do odbioru sygnału o następującej charakterystyce:

1) częstotliwość o wartości nominalnej 225 kHz, transmitowana z nadajnika długofalowego Radiowego Centrum Nadawczego w Solcu Kujawskim, z zastosowaną modulacją amplitudy akustycznego sygnału radiowego oraz systemem dynamicznego sterowania poziomem fali nośnej;
2) zmienny dynamicznie poziom fali nośnej (w zakresie od 0 dB do ok. -6,4 dB względem maksymalnego poziomu fali nośnej) w zależności od głębokości modulacji sygnałem akustycznym (modulacja AM) i ustawionego trybu pracy;
3) możliwe okresowe wyłączenia nadajnika długofalowego 225 kHz na czas przeglądów (średnio raz na rok przez ok. 20 h) i konserwacji (średnio raz na 5 lat przez ok. 2 tygodnie) oraz krótkotrwałe przerwy w emisji sygnału (typowo poniżej 2 h) z innych przyczyn;
4) zaimplementowana modulacja PSK (Phase Shift Keying – kluczowanie fazy) typu NRZ (Non-Return-To-Zero – bez powrotu do zera), sygnał binarny z płynnymi liniowymi zmianami fazy fali nośnej – z możliwością zmiany (w ustalonym ograniczonym zakresie) wybranych parametrów kodowania: wartości głębokości (dodatkowego) przesunięcia fazy fali nośnej przy przejściu do nowego stanu (01 lub 10), czasu realizacji przejścia do nowego stanu (01 lub 10), prędkości transmisji;
5) możliwość okresowego współistnienia dodatkowych ramek o dynamicznie zmienionych parametrach transmisji, długości i zawartości depeszy – modulacja PSK typu NRZ – możliwość zmienionej prędkości transmisji, głębokości (dodatkowego)

Opis przykładowego modułu odbiorczego

przesunięcia fazy fali nośnej, czasu realizacji przejścia do nowego stanu, zmiany kodu korekcji błędów, długości ramki;
6) początek nadawania grupy ramek: o każdej pełnej minucie i kolejne ramki (początek wysyłania) w odstępach co 3 s, możliwe celowe krótkotrwałe przerwy w transmisji ramek stanowiące wielokrotność odstępu 3 s;
7) brak kolizji ramek nadawanych dla potrzeb różnych systemów (harmonogramy nadawania mogą przeplatać się w czasie, ale nie pokrywają się);
8) transmisja każdej pojedynczej ramki trwa krócej niż 3 s;
9) podczas przejścia do nowego stanu maksymalne odchylenie częstotliwości fali nośnej nie przekracza ± 100 Hz;
10) przyjęty podstawowy format modulacji kodowanych sygnałów czasu urzędowego: modulacja PSK typu NRZ, prędkość transmisji 50 bit/s, głębokość (dodatkowego) przesunięcie fazy fali nośnej - 36° ± 3,6° (10 % okresu fali nośnej), długość ramki – 14 bajtów, bajty synchronizujące, niektóre parametry transmisji z czasem mogą ulec niewielkiej modyfikacji, np. głębokość (dodatkowego) przesunięcia fazy fali nośnej, czy czas realizacji przejścia do nowego stanu (01 lub 10);
11) poziom (natężenie pola fali powierzchniowej) odbieranego sygnału 225 kHz z nadajnika długofalowego w RCN w Solcu Kujawskim na większości obszaru Polski szacunkowo wynosi powyżej 78 dB (µV/m) – są obszary, gdzie poziom sygnału maleje lokalnie do poziomu ok 70 dB (µV/m).

### 3 Koncepcja wykonania odbiornika

W odbiorniku można wyróżnić 2 bloki funkcjonalne;
- Frontendu RF - odbiornika częstotliwości radiowej
- demodulatora DSP

Frontend RF oparty jest o układ scalony SI4735, którego schemat blokowy przedstawiono na rysunku 1.

Opis przykładowego modułu odbiorczego

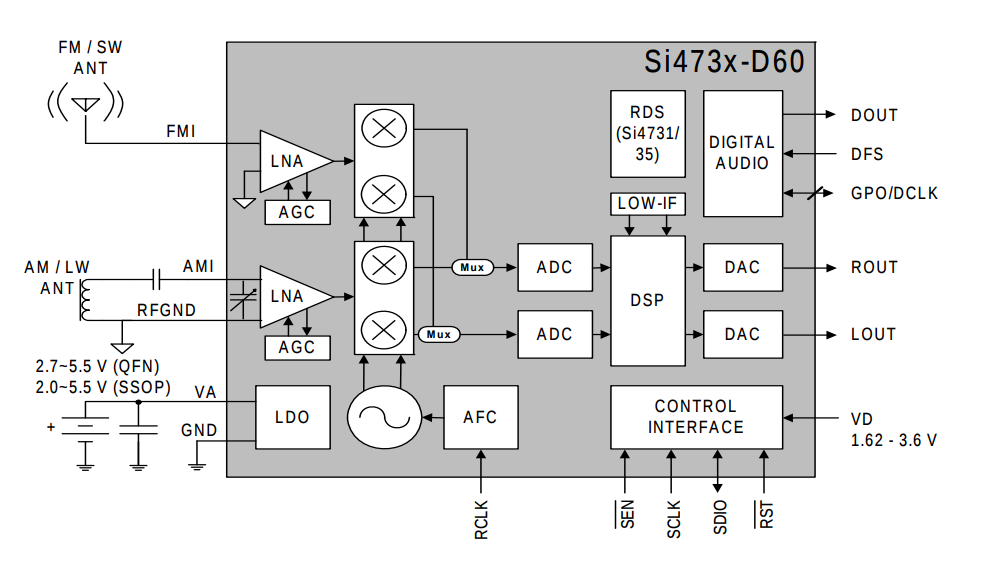
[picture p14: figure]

Rys. 1. Frontend RF przykładowego modułu odbiorczego.

Układ umożliwia odbiór fal długich w zakresie 153-279 kHz, dzięki zastosowaniu procesora DSP możliwe jest niestandardowe wykorzystanie układu i użycie go jako odbiornika SSB (w tym przypadku USB) pracującego z BFO na częstotliwości 224 kHz, co w rezultacie skutkuje odwzorowaniem na wyjściu układu fali nośnej nadajnika przeniesionej do pasma akustycznego - w tym przypadku 1 kHz. Ponadto układ zapewnia automatyczną regulację wzmocnienia. Układ frontendu sterowany jest częstotliwością 32.768 kHz uzyskiwaną z generatora kwarcowego.

Tak odebrany sygnał kierowany jest do dalszej obróbki w procesorze sygnałowym dsPIC33. Po wstępnym przefiltrowaniu przez filtr pasmowo-przepustowy o szerokości 200 Hz. Koncepcja wykonania demodulatora

Podczas obróbki w procesorze DSP odzyskiwana jest informacja z sygnału modulacji PSK, następnie po przejściu przez pakietyzer następuje klasyfikacja ramek. Po wykryciu słowa kluczowego 0x60 kolejne bajty zapisywane są w buforze i przeprowadzona jest korekcja R-S. Następnie przeprowadzana jest weryfikacja poprawności odebranych danych (tzw “sanity checks”) - czy nie wystąpiło “cofnięcie się czasu” ewentualnie “skok w przyszłość” większy niż wynikałoby to z przewidywań na podstawie obserwacji lokalnego RTC.

Pomiar odcinków czasowych pomiędzy kolejnymi odebranymi ramkami, pozwoli na wyznaczenie różnicy częstotliwości i prowadzenie systematycznej korekcji tworzonej w odbiorniku skali czasu.

Po weryfikacji odebranych danych, procesor wysterowuje generator 1PPS.

Opis przykładowego modułu odbiorczego

### 4 Opis bloku DSP

Blok DSP oparty jest na procesorze dsPIC33FJ128GP804. Procesor został wybrany ze względu na wymogi projektowe (zgodnie z zamówieniem, platforma powinna zapewnić możliwość rozbudowy w przyszłości). Proces demodulacji sygnału zajmuje około 10% czasu procesora pozostawiając spory zapas mocy obliczeniowej do przyszłych zastosowań

Na wejście przetwornika analogowo-cyfrowego procesora podany jest sygnał audio z wyjścia tunera. Tego typu rozwiązanie pozwala na rozdzielenie części radiowej od cyfrowej. W bardzo trudnych warunkach odbioru (na przykład na statkach dalekomorskich) można również zastosować profesjonalny odbiornik radiokomunikacyjny i dostarczyć sygnał audio wprost do procesora DSP.

Proces demodulacji ramek czasu przebiega w kilku krokach. Po przefiltrowaniu sygnału przez filtr pasmowo-przepustowy o częstotliwości środkowej 1 kHz i szerokości pasma 200 Hz - sygnał podawany jest na programowo realizowaną pętlę Costasa, która pozwala na wykrycie zmian fazy sygnału. Strumień danych jest następnie przekazany do bit-slicera i tak otrzymany strumień bitów zasila pakietyzer, który analizuje bity synchronizacji i słowo kluczowe.

Po odebraniu ramki danych wyliczane są kody korekcyjne i przeprowadzane testy spójności ramek.

Dodatkowo procesor DSP będzie pełnił rolę zegara RTC.

### 5 Opis ramki danych

W systemie obowiązuje następująca ramka.

5.1Format ramki

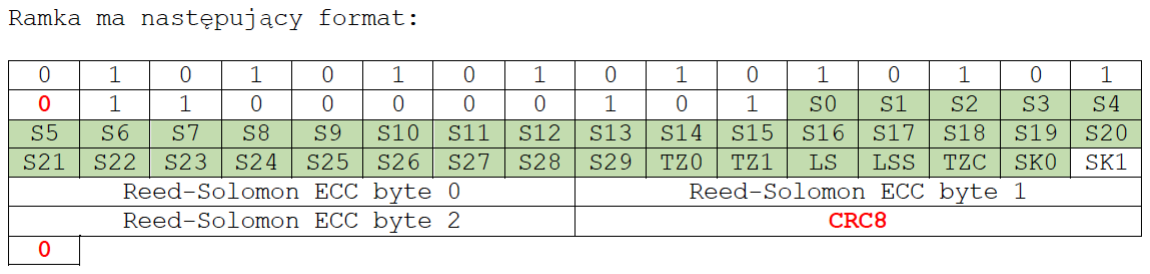
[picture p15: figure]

Tab. 1. Format ramki czasu urzędowego.

Składa się ona z 12 bajtów czyli 96 bitów wysyłanych z przepływnością 50bit/s. Oznacza to,

Opis przykładowego modułu odbiorczego

że wysłanie pełnej ramki czasowej zajmuje 1.92 s. Ramki wysyłane są przez nadajnik w Solcu Kujawskim w slotach czasowych co 3 sekundy. Dzięki temu odbiornik będzie miał sporo czasu na zdemodulowanie i zdekodowanie wysyłanej ramki. Po dwóch bajtach synchronizacyjnych (55H) wysyłany jest znacznik początku 60H, który różni się 7 bitami od znacznika wykorzystywanego przez system Enei do sterowania oświetleniem. W ten sposób oba systemy nie będą kolidowały ze sobą (odbiorniki Enei po wykryciu innego znacznika ignorują całą ramkę. Następnie wysyłane są trzy bity „1-0-1” (5H) z których bit 0 określa ‘umowny’ moment wprowadzenia wysyłanego czasu do rejestrów odbiornika – opóźniony o 0.5 s (25 bitów x 0.02 s = 0.50 s) względem momentu rozpoczęcia nadawania ramki. S0 ÷ S29 Bity (30 bitów) określające ilość trzysekundówek liczonych od 1 stycznia 2000r.,tzn. 3 x (S0 ÷ S29) = liczba sekund liczonych od 1 stycznia 2000 r.

TZ0 TZ1 Bity określające czas lokalny zgodnie z poniższą tabelką:

Tab. 2. Bity określające czas.

5.2Kody korekcyjne
Na końcu ramki czasowej wysyłane są 3 bajty korekcyjne Reeda-Solomona umożliwiające korekcję maksymalnie 24 bitów ramki.

W ramce zaimplementowano kodowanie R-S w wersji:
4b - rozmiar słowa kodowego,
3b - siła korekcji.

Co daje:
Blok danych: 9 słów => 36 bitów,
Blok korekcji: 6 słów => 24 bity.
Korekcji podlegają bity (S0 ÷ SK0) <= 36 bitów - zaznaczone w tabeli. Korekcja nie obejmuje ostatniego bitu danych użytkowych SK1. Ostatni wolny bajt przewidziany został na sumę kontrolną CRC-8.

5.3Scrambling
Dane użytkowe są XOR z binarnym ciągiem 0A 47 55 4D 2B co odpowiada: „\NGUM+”

5.4Format ramki NMEA RMC
Odbiornik systemu e-CzasPL ma za zadanie dostarczać informację o czasie urzędowym.

Opis przykładowego modułu odbiorczego

Aby ułatwić przejście z systemu GNSS do e-CzasPL zastosowano protokół NMEA który symuluje zachowanie odbiornika GNSS. Do synchronizacji czasu zastosowano sentencję RMC (Recommended Minimum Specific GNSS Data). Z oczywistych względów odbiornik nie zna swojego położenia geograficznego, dlatego dla zachowania kompatybilności z odbiornikami GNSS w ramce przesyłane są statyczne współrzędne Laboratorium Czasu i Częstotliwości Głównego Urzędu Miar (52.24183 N, 21.00084 E).

Przykładowa sentencja GPRMC została przedstawiona poniżej:

$GPRMC,120000,A,5214.5098,N,02100.0504,E,0.00,000.0,021123,,E,A*CCCC

NAZWA | PRZYKŁAD | OPIS
ID Sentencji | $GPRMC | Nagłówek NMEA sentencji RMC
czas UTC | 120000 | hhmmss
status | A | A – dane ważne, V – dane nieważne
szerokość geograficzna | 5214.5098 | ddmm.mmmm – pozycja laboratorium GUM
N/S | N | N – szerokość północna, S – szerokość południowa
długość geograficzna | 02100.0504 | dddmm.mmmm - pozycja laboratorium GUM
E/W | E | E – długość wschodnia, W – długość zachodnia
prędkość | 0.00 | Prędkość w węzłach – w tym przypadku pozycja statyczna
kurs | 000.0 | Kurs w stopniach - w tym przypadku pozycja statyczna
data | 021123 | ddmmyy
odchylenie magnetyczna | | w tym przypadku pozycja statyczna
E/W | E | Kierunek odchylenia mag. - pozycja statyczna
Tryb | A | A = Autonomiczny
suma kontrolna | *cccc
<CR><LF> | | Znacznik końca sentencji
Tab. 3. Przykładowa sentencja GPRMC.

Początek sentencji NMEA (znak $) jest wysyłany w momencie początku sekundy umieszczonej w sentencji.

W przypadku zapotrzebowania, możliwa jest modyfikacja oprogramowania układowego odbiornika w taki sposób, aby można było wpisać dowolną pozycję geograficzną podczas konfiguracji odbiornika.

### 5.5 Oprogramowanie wbudowane DSP

Oprogramowanie odbiornika zostało napisane w języku C (główna część) oraz Assembler (część demodulatora) i skompilowane zostało kompilatorem MPLAB XC16 PRO w wersji 2.10 na platformie linux.

Do niniejszej dokumentacji dołączony jest plik HEX gotowy do wgrania do procesora DSP. Do wgrania oprogramowania do procesora konieczny jest jeden z programatorów: PICKIT3, PICKIT4, ICD-3 lub ICD-4. Oprogramowanie można wgrać do mikrokontrolera wlutowanego

Opis przykładowego modułu odbiorczego

w płytkę drukowaną przy pomocy złącza PICKIT.

### 6 Uproszczony Odbiornik sygnału e-CzasPL

Uproszczony odbiornik systemu e-CzasPL zaprojektowany został w taki sposób, aby można go zbudować przy minimalnym zestawie narzędzi. Możliwy jest montaż ręczny, a wymagana jest jedynie podstawowa umiejętność pracy z elementami SMD. Prawidłowo zbudowany układ nie wymaga strojenia ani konfiguracji, urządzenie działa natychmiast po podłączeniu zasilania i jest gotowe do odbioru sygnału czasu.

Odbiornik sygnału e-CzasPL zaprojektowany został jako niezależny moduł, który można zastosować we własnych urządzeniach jako wzorzec czasu urzędowego. Przykładowy projekt odbiornika można zastosować na własne potrzeby w projektach, w których zastosowanie znajduje informacja o czasie odniesionym do czasu urzędowego obowiązującego na obszarze RP.

Odbiornik dostarcza dane o czasie w postaci sentencji NMEA RMC, sygnał 1 PPS oraz surową, nie przetworzoną ramkę danych do obróbki w zewnętrznym systemie.

Odbiornik ma wbudowany zegar RTC który ma za zadanie przetrzymywać czas przez 24h od ostatniej poprawnie odebranej ramki. Po upływie 24h gaszony jest sygnał „FIX” informujący o synchronizacji czasu. Układ nadal będzie podawał zarówno informację o czasie (sentencja NMEA RMC) oraz sygnał 1PPS, jednak nie ma gwarancji co do utrzymania wymaganej zgodności z czasem urzędowym.

### 6.1 Złącze diagnostyczne SV1

Analogicznie do podstawowej wersji odbiornika - na złączu SV1 dostępny jest port UART mikrokontrolera pracujący na poziomach CMOS 3.3V Parametry transmisji 115200 bps 8N1. Na złącze wysyłane są informacje diagnostyczne, w tym surowe ramki w postaci szesnastkowej

### 6.2 Złącze NMEA

Analogicznie do podstawowej wersji odbiornika na złącze SV2 wystawione są dane kompatybilne z formatem NMEA niosące ze sobą informację o czasie. Format NMEA został wybrany ze względu na kompatybilność z urządzeniami kompatybilnymi z odbiornikami GNSS. Opis ramki NMEA znajduje się w rozdziale 5.4. Złącze pracuje na poziomach CMOS 3.3V

### 6.3 Złącze Antenowe

Na złącze antenowe uproszczonego odbiornika należy podać sygnał RF z anteny ferrytowej, bądź z zewnętrznej anteny. Obwód wejściowy frontendu RF jest bardzo tolerancyjny i odporny na niedopasowanie impedancji.

Opis przykładowego modułu odbiorczego

### 6.4 Sygnalizacja stanu pracy Uproszczonego Odbiornika

Na PCB Uproszczonego Odbiornika znajduje się 5 diod LED SMD sygnalizujących stan pracy odbiornika.
- LED1 – zapalana po poprawnym odebraniu ramki danych, przeliczeniu kodów korekcyjnych oraz potwierdzeniu poprawności danych. Narastające zbocze informuje o początku sekundy (przesłanej w ramce danych),
- LED2 – DCD – sygnalizacja rozpoznania początku ramki danych (po wykryciu słowa kluczowego) – pozostaje zapalona do końca transmisji ramki,
- LED3 – Informuje o odebraniu poprawnego czasu i wpisaniu go do RTC, w przypadku braku możliwości aktualizacji RTC z transmisji radiowej dioda jest gaszona po 24 godzinach,
- LED4 – 1PPS Sygnał 1PPS zsynchronizowany z odebranym sygnałem czasu,
- LED5 – sygnalizacja obecności zasilania układu.

Uwaga! Sygnał 1PPS jest ważny (zgodny z czasem urzędowym) tylko kiedy zapalona jest dioda LED3.

### 7 Dokumentacja Wykonawcza Uproszczonego Odbiornika

Układ został zaprojektowany przy pomocy oprogramowania Autodesk Eagle. Pliki schematu, mozaiki ścieżek oraz GERBER do wykonania obwodów PCB są załączone do niniejszej dokumentacji. Układ należy zmontować zwracając uwagę na ułożenie elementów elektronicznych, orientację układów scalonych oraz polaryzację diod LED. Płytka PCB została zaprojektowana w taki sposób, aby ułatwić ręczny montaż elementów.

Nie jest konieczny stencil do nakładania pasty lutowniczej. Montaż przy odrobinie wprawy można przeprowadzić przy pomocy pęsety i klasycznej lutownicy. Bardzo pomocny może okazać się mikroskop albo lupa.

Uproszczony odbiornik został zaprojektowany w ten sposób, aby osoby bez znajomości programowania procesorów DSP, czy technik cyfrowej obróbki sygnałów mogły go zmontować i uruchomić.

Na Rysunku 11 przedstawiono schemat ideowy uproszczonego odbiornika.

Opis przykładowego modułu odbiorczego

### 7.1 Schemat ideowy Uproszczonego Odbiornika

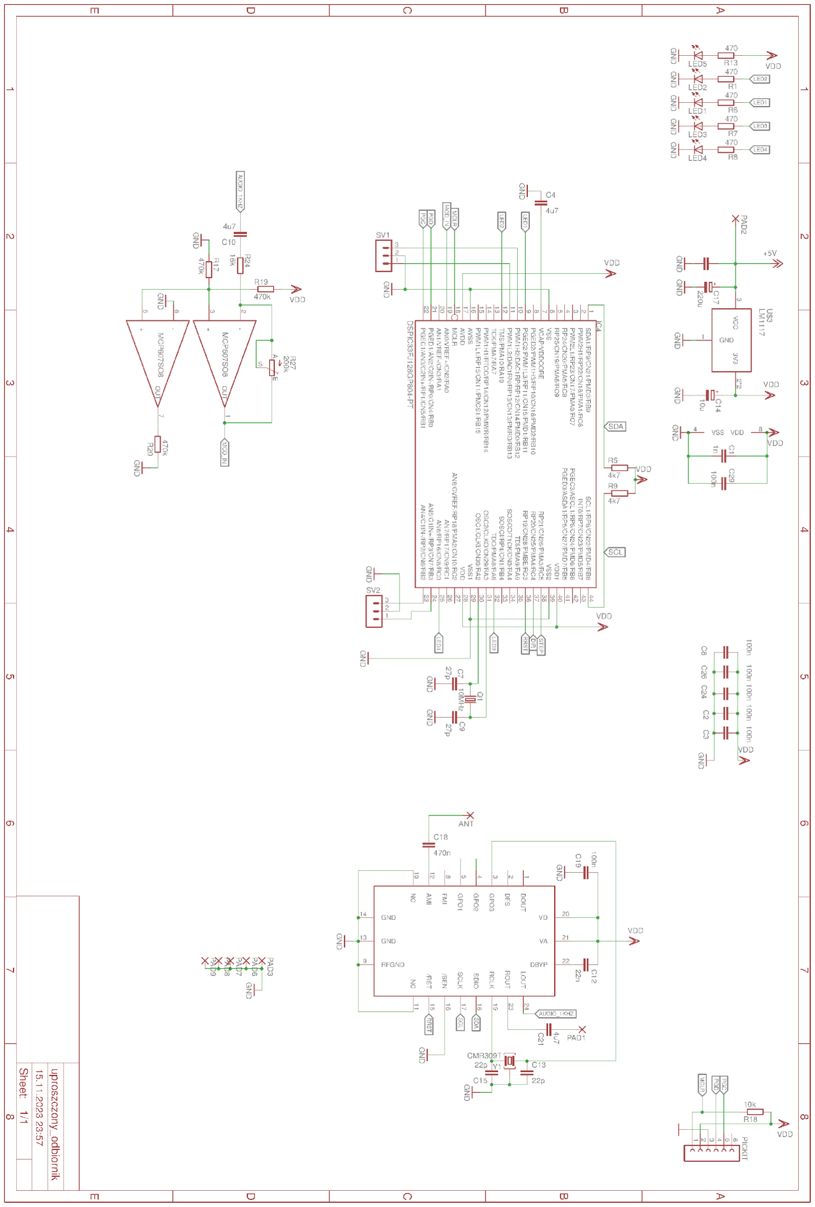
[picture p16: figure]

Rys. 2. Schemat ideowy uproszczonego odbiornika.

Opis przykładowego modułu odbiorczego

### 7.2 Płytka PCB Uproszczonego Odbiornika – strona elementów

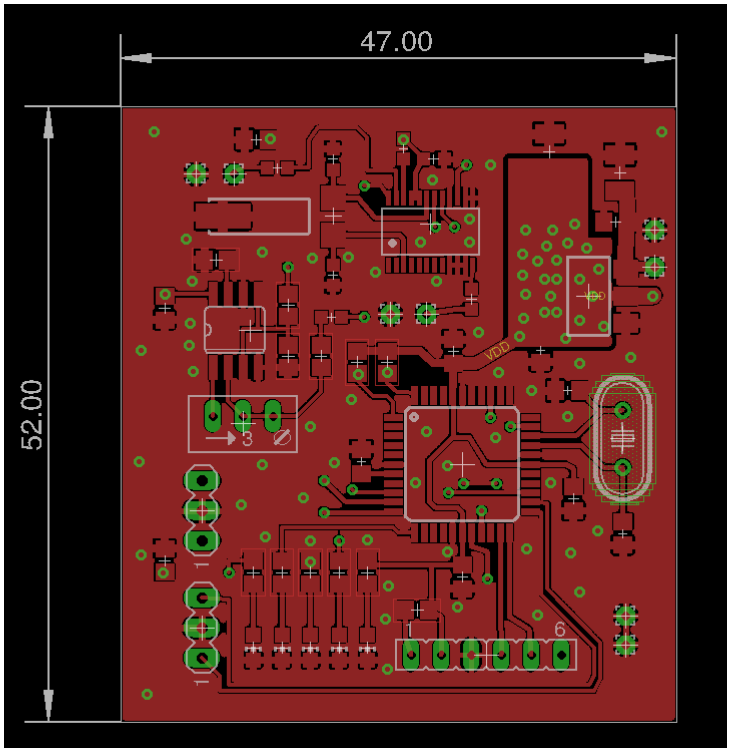
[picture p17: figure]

Rys. 3. Płytka PCB uproszczonego odbiornika – strona elementów.

Opis przykładowego modułu odbiorczego

### 7.3 Płytka PCB Uproszczonego Odbiornika – strona druku

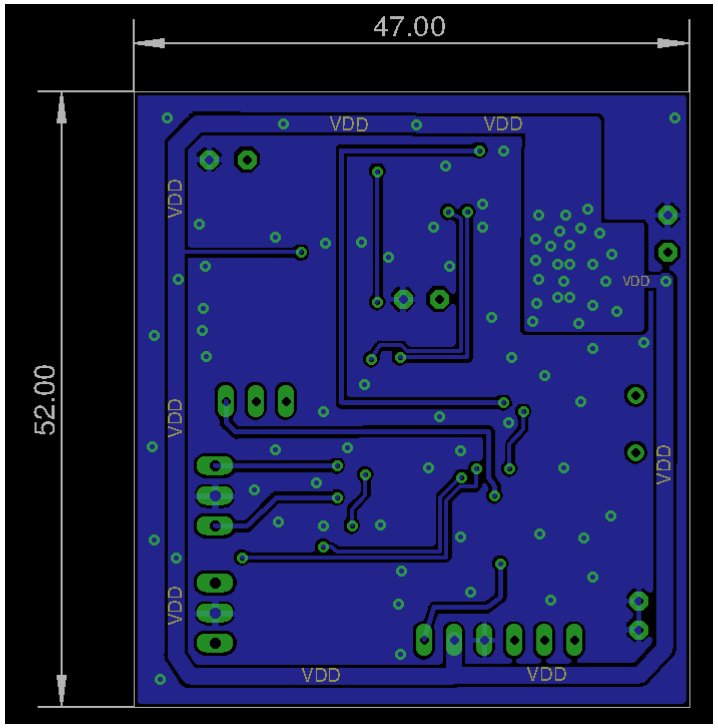
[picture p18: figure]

Rys. 4. Płytka PCB uproszczonego odbiornika – strona druku.

Opis przykładowego modułu odbiorczego

### 7.4 Zestawienie elementów Uproszczonego Odbiornika (BOM)

Element | wartość | Device | Obudowa
C1 | 1n | C-EUC0805K | C0805K
C2 | 100n | C-EUC0805K | C0805K
C3 | 100n | C-EUC0805K | C0805K
C4 | 4u7 | C-EUC0805K | C0805K
C5 | 100n | C-EUC0805K | C0805K
C7 | 27p | C-EUC0805K | C0805K
C8 | 100n | C-EUC0805K | C0805K
C9 | 27p | C-EUC0805K | C0805K
C10 | 4u7 | C-EUC0603K | C0603K
C12 | 22n | C-EUC0603K | C0603K
C13 | 22p | C-EUC0603K | C0603K
C14 | 10u | CPOL-EUSMCB | SMC_B
C15 | 22p | C-EUC0603K | C0603K
C17 | 220u | CPOL-EUSMCB | SMC_B
C18 | 470n | C-EUC0603K | C0603K
C19 | 100n | C-EUC0603K | C0603K
C21 | 4u7 | C-EUC0603K | C0603K
C24 | 100n | C-EUC0805K | C0805K
C26 | 100n | C-EUC0805K | C0805K
C29 | 100n | C-EUC0805K | C0805K
IC4 | DSPIC33FJ128GP804-PT | DSPIC33FJ128M | C804-PT TQFP44
LED1 | LED | LEDCHIP-LED0 | 805 CHIP-LED0805
LED2 | LED | LEDCHIP-LED0 | 805 CHIP-LED0805
LED3 | LED | LEDCHIP-LED0 | 805 CHIP-LED0805
LED4 | LED | LEDCHIP-LED0 | 805 CHIP-LED0805
LED5 | LED | LEDCHIP-LED0 | 805 CHIP-LED0805
PICKIT | złącze pinowe 2.54x6 | FE06-1 | FE06
Q1 | kwarc 10MHz | CRYSTALHC49U | HC49U-V
R1 | 470 | R-EU_R0805 | R0805
R5 | 4k7 | R-EU_R0805 | R0805
R6 | 470 | R-EU_R0805 | R0805
R7 | 470 | R-EU_R0805 | R0805
R8 | 470 | R-EU_R0805 | R0805
R9 | 4k7 | R-EU_R0805 | R0805

Opis przykładowego modułu odbiorczego

R13 | 470 | R-EU_R0805 | R0805
R17 | 470k | R-EU_M0805 | M0805
R18 | 10k | R-EU_R0805 | R0805
R19 | 470k | R-EU_M0805 | M0805
R20 | 470k | R-EU_M0805 | M0805
R24 | 18k | R-EU_M0805 | M0805
R27 | 200k | TRIM_EU-RJ9W | RJ9W
SV1 | złącze pinowe 2.54 mmx3 | MA03-1 | MA03-1
SV2 | złącze pinowe 2.54 mmx3 | MA03-1 | MA03-1
U$1 | MCP607SO8 | MCP607SO8 | SOIC8
U$3 | LM1117 | LM1117 | SOT223-3
U$5 | SI4735-D60 | SI4735-D60 | SSOP24
Y1 | kwarc 32.768 kHz | CMR309T | CMR309T
Tabela 2

### 7.5 Oprogramowanie układowe Uproszczonego Odbiornika

Uproszczony Odbiornik pracuje w oparciu o to samo oprogramowanie układowe co podstawowa wersja odbiornika. Analogicznie do podstawowej wersji odbiornika oprogramowanie należy wgrać do procesora DSP przy pomocy jednego z programatorów: PICKIT3, PICKIT4, ICD-3 lub ICD-4. Oprogramowanie należy wgrać do procesora po jego umieszczeniu na płytce PCB podłączając programator do złącza PICKIT.

Oprogramowanie podczas startu urządzenia automatycznie rozpozna czy pracuje w podstawowej, czy uproszczonej wersji odbiornika i podejmie odpowiednie akcje.

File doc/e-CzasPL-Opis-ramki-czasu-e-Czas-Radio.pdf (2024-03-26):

Dystrybucja czasu urzędowego Struktura ramki, przesyłane dane i ich przeznaczenie


## Dystrybucja czasu urzędowego na falach długich, przy wykorzystaniu fali nośnej 225 kHz Programu Pierwszego Polskiego Radia

## struktura ramki, przesyłane dane i ich przeznaczenie

v. 1.0

str. 1

Struktura ramki, przesyłane dane i ich przeznaczenie

I. Schemat działania systemu:
Transmisja w systemie zorganizowana jest w slotach czasowych 3 s. Komunikaty wysyłane są z przepływnością 50 b/s. W każdym slocie czasowym transmisja rozpoczyna się od początku sekundy. Po każdej przesłanej komendzie system wyłącza modulacje fazy nośnej do kolejnej pełnej sekundy. Ruch generowany przez Radiowe Centrum Nadawcze (RCN) odbywa się w 20 slotach czasowych (od 0 do 19). Stanowią one ramkę, która transportowana jest przez 1 minutę (ramka minutowa).
Numer slotu | Czas od początku emisji [s] | Przeznaczenie
0 | 0 | Komunikat zegarowy 0
1 | 3 | Komunikat 1
2 | 6 | Komunikat 2
3 | 9 | Komunikat 3
⋮ | ⋮ | ⋮
18 | 54 | Komunikat 18
19 | 57 | Komunikat 19

Rys. 1 Ramka minutowa systemu.

Struktura ramki, przesyłane dane i ich przeznaczenie

II. Struktura ramki czasu urzędowego:
Ramka czasu składa się z 12 bajtów czyli 96 bitów wysyłanych z przepływnością 50bit/s. Oznacza to, że wysłanie pełnej ramki czasowej zajmuje 1.92 s.

NR
BAJTU
1

### 16 b → CIĄG SYNCHRONIZACYJNY

2

3 8 b → ZNACZNIK POCZĄTKU RAMKI CZASU

4

### 3 b → CZAS WEJŚCIA DO ODBIORNIKA

### 30 b → CZAS URZĘDOWY

5

6

7

8

### 2 b → CZAS LOKALNY

### 1 b → ZAPOWIEDŹ SEKUNDY PRZESTĘPNEJ

### 1 b → ZNAK SEKUNDY PRZESTĘPNEJ

### 1 b → ZMIANA CZASU LOKALNEGO

### 2 b → STAN NADAJNIKA DŁUGOFALOWEGO

9

10 24 b → KODY KOREKCYJNE REEDA-SOLOMONA

11

12 8 b → SUMA KONTROLNA CRC-8

Rys. 2 Struktura blokowa depeszy czasowej.

Struktura ramki, przesyłane dane i ich przeznaczenie

Przed każdą ramką transmitowane są ponadto 2 B (0x680C – 0b0110 0b1000 0b0000 0b1100) będące sekwencją startu. Nie są one częścią depeszy czasowej. Poniżej przedstawiono format ramki w postaci bitowej:

Rys. 3 Struktura bitowa depeszy czasowej.
Przeznaczenie poszczególnych bitów:
- 0x55H | - stały wzorzec synchronizacyjny;
- 0x60H - stały wzorzec sygnalizujący początek ramki czasu urzędowego
dystrybuowanej w ramach „e-CzasPL”;
- | 0x5H (0b101) | - bity określające moment wprowadzenia
wysyłanego czasu do rejestrów odbiornika – opóźniony o 0.5 s (25b × 0.02 s = 0.50 s) względem momentu rozpoczęcia nadawania ramki;
- | S0 ÷ S29 | - bity określające ilość okresów trzysekundowych
| liczonych
od 1 stycznia 2000 r. (3 × (S0 ÷ S29) = liczba sekund liczonych od 1 stycznia 2000 r.;
- | TZ0 ÷ TZ1 | - bity określające czas lokalny; w celu obliczenia
czasu lokalnego należy dodać do czasu odebranego z ramki czasowej odpowiedni offset określony przez bity TZ0 i TZ1 (wg poniższej tabeli);
TZ0 | TZ1 | Czas lokalny
0 | 0 | 0
1 | 0 | +1 godzina
0 | 1 | +2 godziny
1 | 1 | +3 godziny
- | LS | - bit oznaczający, że nadawana jest zapowiedź/brak
zapowiedzi sekundy przestępnej:
0 – brak zapowiedzi sekundy przestępnej,
0 | 1 | 0 | 1 | 0 | 1 | 0 | 1 | 0 | 1 | 0 | 1 | 0 | 1 | 0 | 1
0 | 1 | 1 | 0 | 0 | 0 | 0 | 0 | 1 | 0 | 1 | S0 | S1 | S2 | S3 | S4
S5 | S6 | S7 | S8 | S9 | S10 | S11 | S12 | S13 | S14 | S15 | S16 | S17 | S18 | S19 | S20
S21 | S22 | S23 | S24 | S25 | S26 | S27 | S28 | S29 | TZ0 | TZ1 | LS | LSS | TZC | SK0 | SK1
Reed-Solomon ECC byte 0 | | | | | | | | Reed-Solomon ECC byte 1
Reed-Solomon ECC byte 2 | | | | | | | | CRC-8

Struktura ramki, przesyłane dane i ich przeznaczenie

1 – zapowiedź wprowadzenia sekundy przestępnej;
sekunda przestępna może być wprowadzona na początku kwartału:
I wariant – 1 stycznia lub 1 lipca,
II wariant – 1 kwietnia lub 1 października
o godz. 0:00 UTC; zapowiedź sekundy przestępnej powinna być nadawana w okresie od kilku dni do maksymalnie 1 tygodnia
przed | planowanym | momentem | wprowadzenia | sekundy
przestępnej;
- LSS - bit określający znak sekundy przestępnej:
0 – dodanie sekundy,
1 – odjęcie sekundy;
- TZC - bit informujący, ze w najbliższą niedzielę o godz. 1:00 UTC nastąpi zmiana czasu lokalnego na letni lub zimowy/zwykły; domyślnie zmiana czasu następuje w ostatnią niedzielę marca (zmiana na czas letni) oraz w ostatnią niedzielę października (zmiana na czas zimowy/zwykły); zapowiedź zbliżającej się zmiany czasu powinna być nadawana z wyprzedzeniem do kilku dni (maksymalnie
do 6 dni) przed planowaną zmianą czasu lokalnego;
- SK0 ÷ SK1 - bity określające stan nadajnika w Solcu Kujawskim wg poniższej tabeli:
SK0 | SK1 | Stan nadajnika w Solcu Kujawskim
0 | 0 | Praca normalna
1 | 0 | Planowane wyłączenie na 1 dzień
0 | 1 | Planowane wyłączenie na tydzień
1 | 1 | Planowane wyłączenie na dłużej niż tydzień

Na końcu ramki czasowej wysyłane są 3 bajty korekcyjne Reeda-Solomona umożliwiające korekcję maksymalnie 24 bitów ramki. Bity będące objęte korekcją

III. Kodowanie korekcyjne Reeda-Solomona:
Zaimplementowany algorytm Reeda-Solomona może objąć korekcją 36 bitów. Korekcją obejmowane są bity S0 ÷ SK0 (oznaczone na rys. 1. zielonym kolorem). UWAGA
Korekcją nie jest objęty ostatni bit danych użytkowych SK1 (patrz. rys. 1). UWAGA
Blok korekcji składa się z 24 nadmiarowych bitów (bajty 9 ÷ 11).

IV. Suma kontrolna i scrambling:
Ostatni wolny bajt przewidziany został na sumę kontrolną CRC-8.

Struktura ramki, przesyłane dane i ich przeznaczenie

UWAGA
W poprzedniej wersji ramki czasowej przewidywano 4 bajty algorytmu korekcji R-S (zmiana po ustaleniach 04.09).

Struktura ramki, przesyłane dane i ich przeznaczenie

UWAGA
Suma kontrolna jest wyliczana na podstawie pełnych bajtów 4 ÷ 8 (bity 25 ÷ 64)
po scramblingu. W procesie scramblingu dane są poddawane operacji XOR
z ciągiem 0x0A47554D2B co w kodzie ASCII odpowiada: \NGUM+. Descrambling realizuje się poprzez ponowne powtórzenie tej operacji.

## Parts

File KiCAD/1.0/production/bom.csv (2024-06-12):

Designator | Footprint | Quantity | Value | LCSC Part #
ANT0, PAD1, PAD2, PAD3, PAD6, PAD7, PAD8, PAD9 | 1,6_0,9 | 8 | 1,6/0,9
C1 | C0805K | 1 | 1n
C10, C21 | C0603K | 2 | 4u7
C12 | C0603K | 1 | 22n
C13, C15 | C0603K | 2 | 22p
C14 | SMC_B | 1 | 10u
C17 | SMC_B | 1 | 220u
C18 | C0603K | 1 | 470n
C19 | C0603K | 1 | 100n
C2, C24, C26, C29, C3, C5, C8 | C0805K | 7 | 100n
C4 | C0805K | 1 | 4u7
C7, C9 | C0805K | 2 | 27p
IC4 | TQFP44 | 1 | DSPIC33FJ64MC804-PT
LED1, LED2, LED3, LED4, LED5 | CHIP-LED0805 | 5 | LEDCHIP-LED0805
PICKIT0 | FE06 | 1 | FE06-1
Q1 | HC49U-V | 1 | 10MHz
R1, R13, R6, R7, R8 | R0805 | 5 | 470
R17, R19, R20 | M0805 | 3 | 470k
R18 | R0805 | 1 | 10k
R2 | R0805 | 1 | 20k
R24 | M0805 | 1 | 18k
R27 | RJ9W | 1 | 200k
R5, R9 | R0805 | 2 | 4k7
SV1, SV2 | MA03-1 | 2 | MA03-1
U$1 | SOIC8 | 1 | MCP607SO8
U$3 | SOT223-3 | 1 | LM1117
U$5 | SSOP24 | 1 | SI4735-D60
Y1 | CMR309T | 1 | CMR309T

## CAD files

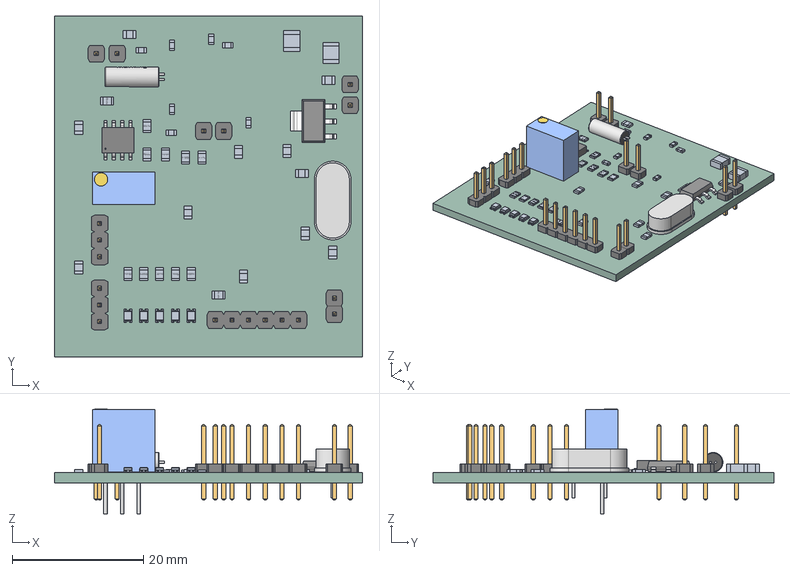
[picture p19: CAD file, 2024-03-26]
KiCAD/1.0/uproszczony_odbiornik.step
47.0 x 52.0 x 16.0 mm
Assem1 x 25
6130xx11121 x 11
DCY0004A_ASM
quartz
_autosave-uproszczony_odbiornik_PCB

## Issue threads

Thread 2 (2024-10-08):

DSP mismatch on schematic?

maghostmil, 2024-10-08:
All docs refers DSPIC33FJ128MC804-PT, but DSPIC33FJ64MC804-PT on the schema.
It's a bug or .hex is compatible with 64 version?

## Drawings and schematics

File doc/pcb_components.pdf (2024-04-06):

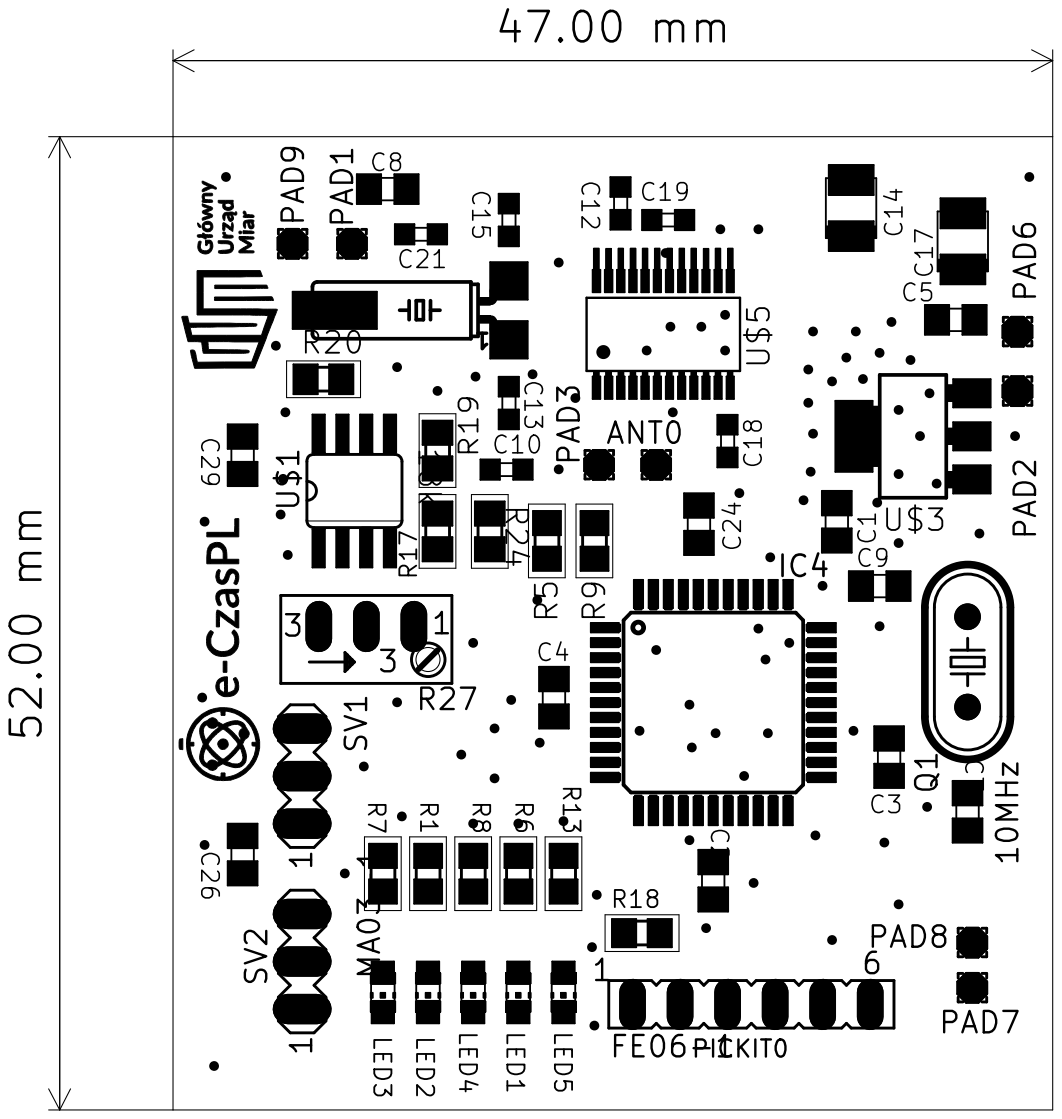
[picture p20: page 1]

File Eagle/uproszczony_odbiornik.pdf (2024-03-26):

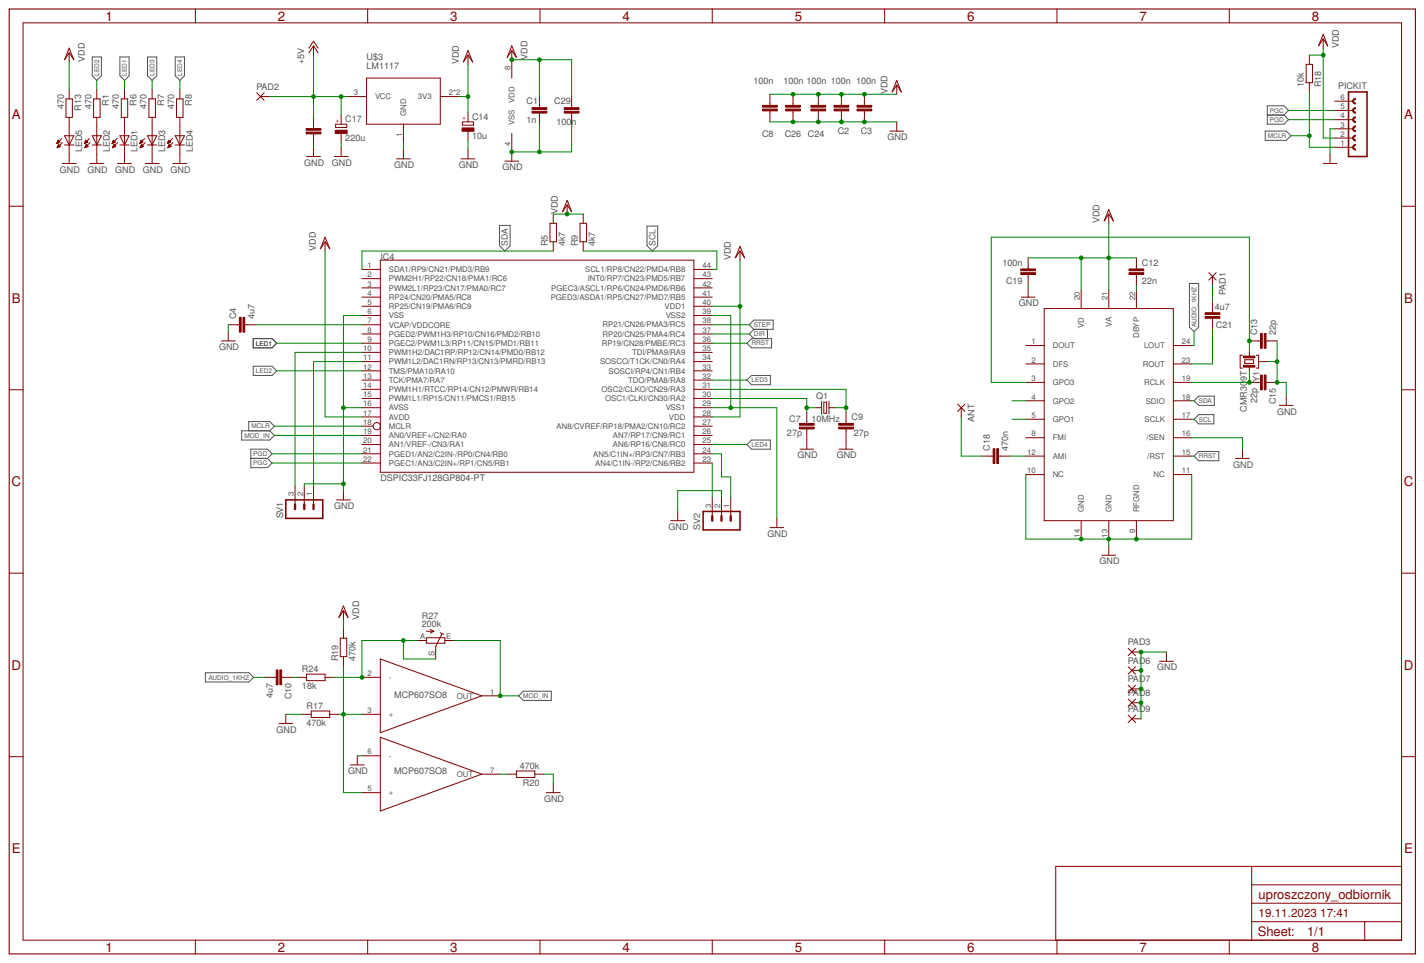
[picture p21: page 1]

PGD | 4

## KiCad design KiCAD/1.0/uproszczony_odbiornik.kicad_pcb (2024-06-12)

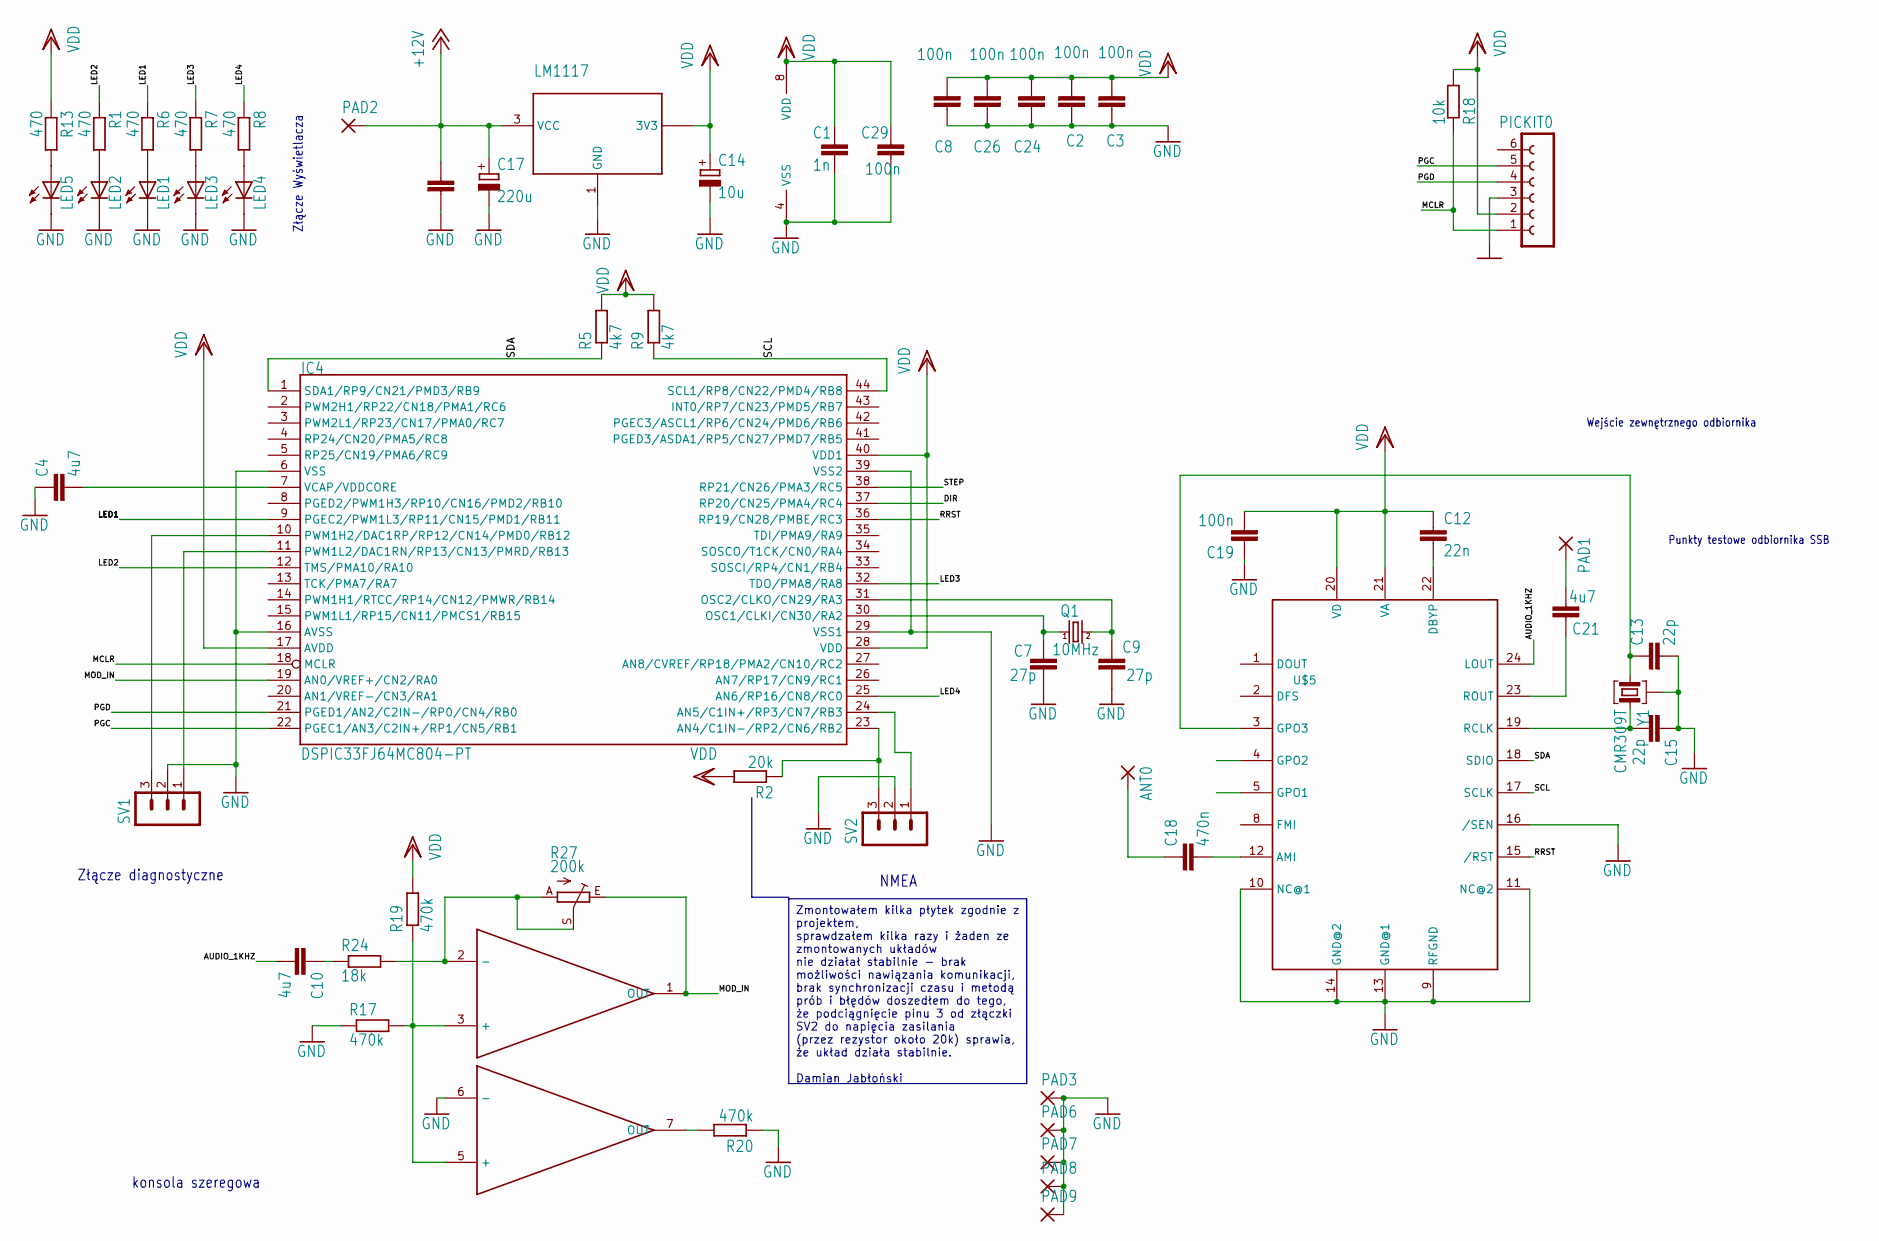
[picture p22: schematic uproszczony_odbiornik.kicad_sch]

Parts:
ANT0: 1,6/0,9; 1,6_0,9
C1: 1n; C0805K
C2, C3, C5, C8, C24, C26, C29: 100n; C0805K
C4: 4u7; C0805K
C7, C9: 27p; C0805K
C10, C21: 4u7; C0603K
C12: 22n; C0603K
C13, C15: 22p; C0603K
C14: 10u; SMC_B
C17: 220u; SMC_B
C18: 470n; C0603K
C19: 100n; C0603K
IC4: DSPIC33FJ64MC804-PT; TQFP44
LED1, LED2, LED3, LED4, LED5: LEDCHIP-LED0805; CHIP-LED0805
PAD1, PAD2, PAD3, PAD6, PAD7, PAD8, PAD9: 1,6/0,9; 1,6_0,9
PICKIT0: FE06-1; FE06
Q1: 10MHz; HC49U-V
R1, R6, R7, R8, R13: 470; R0805
R2: 20k; R0805
R5, R9: 4k7; R0805
R17, R19, R20: 470k; M0805
R18: 10k; R0805
R24: 18k; M0805
R27: 200k; RJ9W
SV1, SV2: MA03-1
U$1: MCP607SO8; SOIC8
U$3: LM1117; SOT223-3
U$5: SI4735-D60; SSOP24
Y1: CMR309T

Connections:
+12V: C5.1, C17.+, PAD2.1, U$3.3 (VCC)
/AUDIO_1KHZ: C10.2, U$5.24 (LOUT)
/DIR: IC4.37 (RP20/CN25/PMA4/RC4)
/LED1: IC4.9 (PGEC2/PWM1L3/RP11/CN15/PMD1/RB11), R6.1
/LED2: IC4.12 (TMS/PMA10/RA10), R1.1
/LED3: IC4.32 (TDO/PMA8/RA8), R7.1
/LED4: IC4.25 (AN6/RP16/CN8/RC0), R8.1
/MCLR: IC4.18 (MCLR), PICKIT0.1, R18.1
/MOD_IN: IC4.19 (AN0/VREF+/CN2/RA0), R27.E, U$1.1 (OUT)
/PGC: IC4.22 (PGEC1/AN3/C2IN+/RP1/CN5/RB1), PICKIT0.5
/PGD: IC4.21 (PGED1/AN2/C2IN-/RP0/CN4/RB0), PICKIT0.4
/RRST: IC4.36 (RP19/CN28/PMBE/RC3), U$5.15 (/RST)
/SCL: IC4.44 (SCL1/RP8/CN22/PMD4/RB8), R9.1, U$5.17 (SCLK)
/SDA: IC4.1 (SDA1/RP9/CN21/PMD3/RB9), R5.1, U$5.18 (SDIO)
/STEP: IC4.38 (RP21/CN26/PMA3/RC5)
GND: C1.2, C2.2, C3.2, C4.1, C5.2, C7.2, C8.1, C9.2, C13.2, C14.-, C15.1, C17.-, C19.1, C24.1, C26.1, C29.2, IC4.6 (VSS), IC4.16 (AVSS), IC4.29 (VSS1), IC4.39 (VSS2), LED1.C, LED2.C, LED3.C, LED4.C, LED5.C, PAD3.1, PAD6.1, PAD7.1, PAD8.1, PAD9.1, PICKIT0.3, R17.1, R20.1, SV1.2, SV2.2, U$1.4 (VSS), U$1.6 (-), U$3.1 (GND), U$5.9 (RFGND), U$5.10 (NC@1), U$5.11 (NC@2), U$5.13 (GND@1), U$5.14 (GND@2), U$5.16 (/SEN), Y1.3 (G)
unnamed: ANT0.1, C18.1
unnamed: C10.1, R24.1
unnamed: IC4.23 (AN4/C1IN-/RP2/CN6/RB2), R2.1, SV2.3
unnamed: IC4.24 (AN5/C1IN+/RP3/CN7/RB3), SV2.1
unnamed: C7.1, IC4.30 (OSC1/CLKI/CN30/RA2), Q1.1
unnamed: C9.1, IC4.31 (OSC2/CLKO/CN29/RA3), Q1.2
unnamed: IC4.10 (PWM1H2/DAC1RP/RP12/CN14/PMD0/RB12), SV1.3
unnamed: IC4.11 (PWM1L2/DAC1RN/RP13/CN13/PMRD/RB13), SV1.1
unnamed: C4.2, IC4.7 (VCAP/VDDCORE)
unnamed: LED1.A, R6.2
unnamed: LED2.A, R1.2
unnamed: LED3.A, R7.2
unnamed: LED4.A, R8.2
unnamed: LED5.A, R13.2
unnamed: C21.2, PAD1.1
unnamed: R17.2, R19.1, U$1.3 (+), U$1.5 (+)
unnamed: R24.2, R27.A, R27.S, U$1.2 (-)
unnamed: R20.2, U$1.7 (OUT)
unnamed: C18.2, U$5.12 (AMI)
unnamed: C12.2, U$5.22 (DBYP)
unnamed: C13.1, U$5.3 (GPO3), Y1.1
unnamed: C15.2, U$5.19 (RCLK), Y1.2
unnamed: C21.1, U$5.23 (ROUT)
VDD: C1.1, C2.1, C3.1, C8.2, C12.1, C14.+, C19.2, C24.2, C26.2, C29.1, IC4.17 (AVDD), IC4.28 (VDD), IC4.40 (VDD1), PICKIT0.2, R2.2, R5.2, R9.2, R13.1, R18.2, R19.2, U$1.8 (VDD), U$3.2 (3V3), U$3.4 (3V3), U$5.20 (VD), U$5.21 (VA)

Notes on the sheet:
Zmontowałem kilka płytek zgodnie z projektem, sprawdzałem kilka razy i żaden ze zmontowanych układów nie działał stabilnie - brak możliwości nawiązania komunikacji, brak synchronizacji czasu i metodą prób i błędów doszedłem do tego, że podciągnięcie pinu 3 od złączki SV2 do napięcia zasilania (prze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
Złącze diagnostyczne
Wejście zewnętrznego odbiornika
Złącze Wyświetlacza
Punkty testowe odbiornika SSB
konsola szeregowa
NMEA

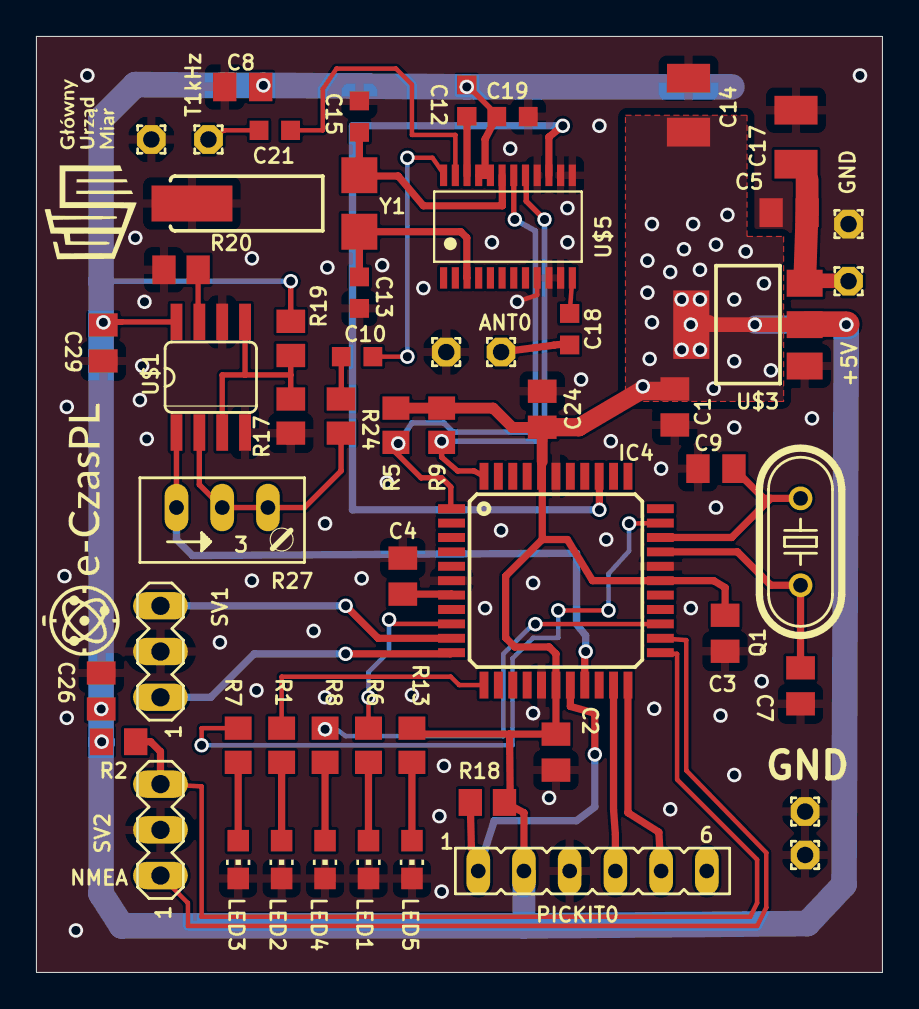
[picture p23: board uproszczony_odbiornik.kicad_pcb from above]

Board: 2 copper layers, 47.0 x 52.0 mm, 56 parts (0 on the bottom side), 38 nets.

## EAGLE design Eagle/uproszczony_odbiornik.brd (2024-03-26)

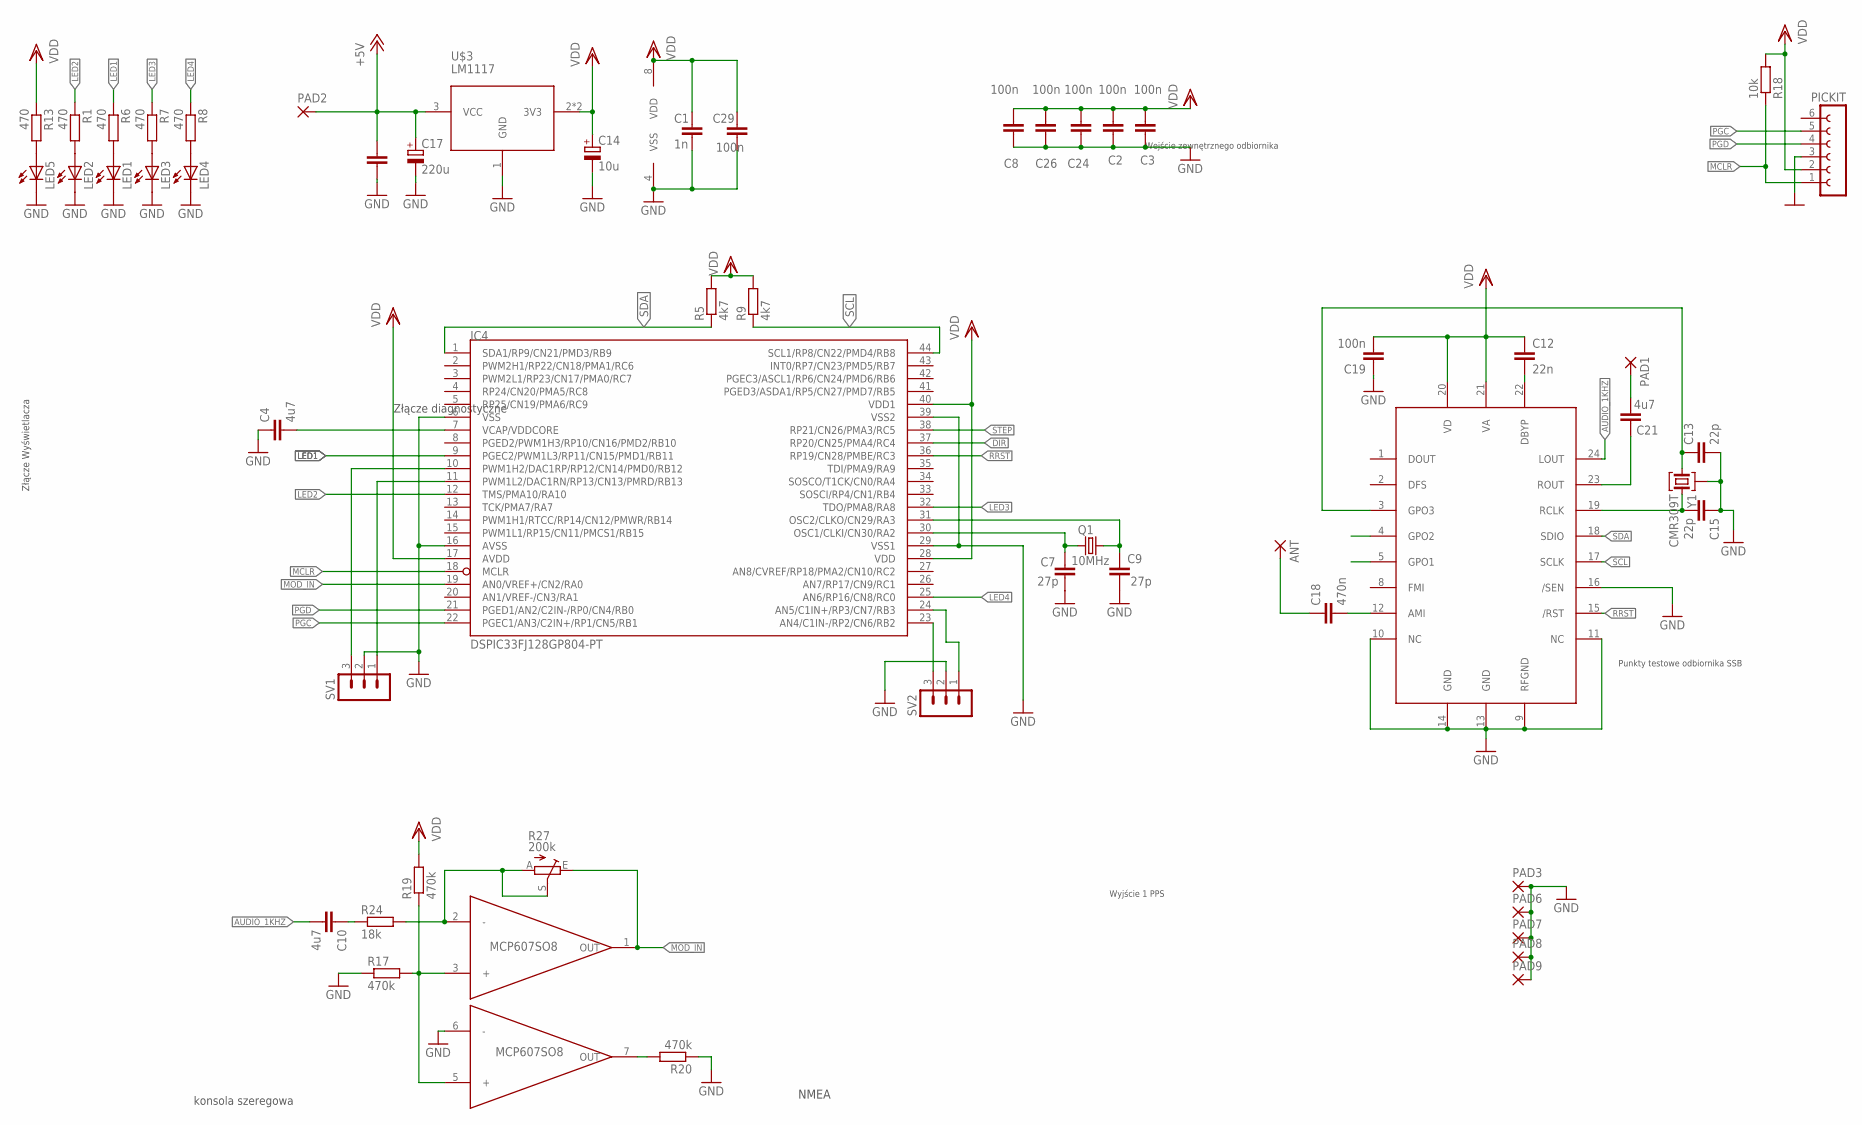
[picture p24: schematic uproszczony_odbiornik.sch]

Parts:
ANT: 1,6/0,9
C1: 1n; C0805K
C2, C3, C5, C8, C24, C26, C29: 100n; C0805K
C4: 4u7; C0805K
C7, C9: 27p; C0805K
C10, C21: 4u7; C0603K
C12: 22n; C0603K
C13, C15: 22p; C0603K
C14: 10u; SMC_B
C17: 220u; SMC_B
C18: 470n; C0603K
C19: 100n; C0603K
IC4: DSPIC33FJ128GP804-PT; TQFP44
LED1, LED2, LED3, LED4, LED5: LEDCHIP-LED0805; CHIP-LED0805
PAD1, PAD2, PAD3, PAD6, PAD7, PAD8, PAD9: 1,6/0,9
PICKIT: FE06-1; FE06
Q1: 10MHz; HC49U-V
R1, R6, R7, R8, R13: 470; R0805
R5, R9: 4k7; R0805
R17, R19, R20: 470k; M0805
R18: 10k; R0805
R24: 18k; M0805
R27: 200k; RJ9W
SV1, SV2: MA03-1
U$1: MCP607SO8; SOIC8
U$3: LM1117; SOT223-3
U$5: SI4735-D60; SSOP24
Y1: CMR309T

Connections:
10MHZ: C7.1, IC4.30 (OSC1/CLKI/CN30/RA2), Q1.1
+5V: C5.1, C17.+, PAD2.1, U$3.3 (VCC)
AUDIO_1KHZ: C10.2, U$5.24 (LOUT)
CON_OUT: IC4.10 (PWM1H2/DAC1RP/RP12/CN14/PMD0/RB12), SV1.3
CON_RX: IC4.11 (PWM1L2/DAC1RN/RP13/CN13/PMRD/RB13), SV1.1
DBYP: C12.2, U$5.22 (DBYP)
DIR: IC4.37 (RP20/CN25/PMA4/RC4)
GND: C1.2, C2.2, C3.2, C4.1, C5.2, C7.2, C8.1, C9.2, C13.2, C14.-, C15.1, C17.-, C19.1, C24.1, C26.1, C29.2, IC4.6 (VSS), IC4.16 (AVSS), IC4.29 (VSS1), IC4.39 (VSS2), LED1.C, LED2.C, LED3.C, LED4.C, LED5.C, PAD3.1, PAD6.1, PAD7.1, PAD8.1, PAD9.1, PICKIT.3, R17.1, R20.1, SV1.2, SV2.2, U$1.4 (VSS), U$1.6 (-), U$3.1 (GND), U$5.9 (RFGND), U$5.10 (NC), U$5.11 (NC), U$5.13 (GND), U$5.14 (GND), U$5.16 (/SEN), Y1.3 (G)
GPO1: U$5.5 (GPO1)
GPO2: U$5.4 (GPO2)
GPO3: C13.1, U$5.3 (GPO3), Y1.1
LED1: IC4.9 (PGEC2/PWM1L3/RP11/CN15/PMD1/RB11), R6.1
LED2: IC4.12 (TMS/PMA10/RA10), R1.1
LED3: IC4.32 (TDO/PMA8/RA8), R7.1
LED4: IC4.25 (AN6/RP16/CN8/RC0), R8.1
MCLR: IC4.18 (MCLR), PICKIT.1, R18.1
MOD_IN: IC4.19 (AN0/VREF+/CN2/RA0), R27.E, U$1.1 (OUT)
unnamed: LED2.A, R1.2
unnamed: R20.2, U$1.7 (OUT)
unnamed: C9.1, IC4.31 (OSC2/CLKO/CN29/RA3), Q1.2
unnamed: C21.2, PAD1.1
unnamed: ANT.1, C18.1
unnamed: R17.2, R19.1, U$1.3 (+), U$1.5 (+)
unnamed: R24.2, R27.A, R27.S, U$1.2 (-)
unnamed: LED3.A, R7.2
unnamed: LED4.A, R8.2
unnamed: LED1.A, R6.2
unnamed: C18.2, U$5.12 (AMI)
unnamed: C10.1, R24.1
unnamed: LED5.A, R13.2
NMEA_RX: IC4.23 (AN4/C1IN-/RP2/CN6/RB2), SV2.3
NMEA_TX: IC4.24 (AN5/C1IN+/RP3/CN7/RB3), SV2.1
PGC: IC4.22 (PGEC1/AN3/C2IN+/RP1/CN5/RB1), PICKIT.5
PGD: IC4.21 (PGED1/AN2/C2IN-/RP0/CN4/RB0), PICKIT.4
RCLK: C15.2, U$5.19 (RCLK), Y1.2
ROUT: C21.1, U$5.23 (ROUT)
RRST: IC4.36 (RP19/CN28/PMBE/RC3), U$5.15 (/RST)
SCL: IC4.44 (SCL1/RP8/CN22/PMD4/RB8), R9.1, U$5.17 (SCLK)
SDA: IC4.1 (SDA1/RP9/CN21/PMD3/RB9), R5.1, U$5.18 (SDIO)
STEP: IC4.38 (RP21/CN26/PMA3/RC5)
VCAP/VDDCORE: C4.2, IC4.7 (VCAP/VDDCORE)
VDD: C1.1, C2.1, C3.1, C8.2, C12.1, C14.+, C19.2, C24.2, C26.2, C29.1, IC4.17 (AVDD), IC4.28 (VDD), IC4.40 (VDD1), PICKIT.2, R5.2, R9.2, R13.1, R18.2, R19.2, U$1.8 (VDD), U$3.2 (3V3), U$3.4 (3V3), U$5.20 (VD), U$5.21 (VA)

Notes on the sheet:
NMEA
Punkty testowe odbiornika SSB
Wyjście 1 PPS
Wejście zewnętrznego odbiornika
Złącze Wyświetlacza
Złącze diagnostyczne
konsola szeregowa

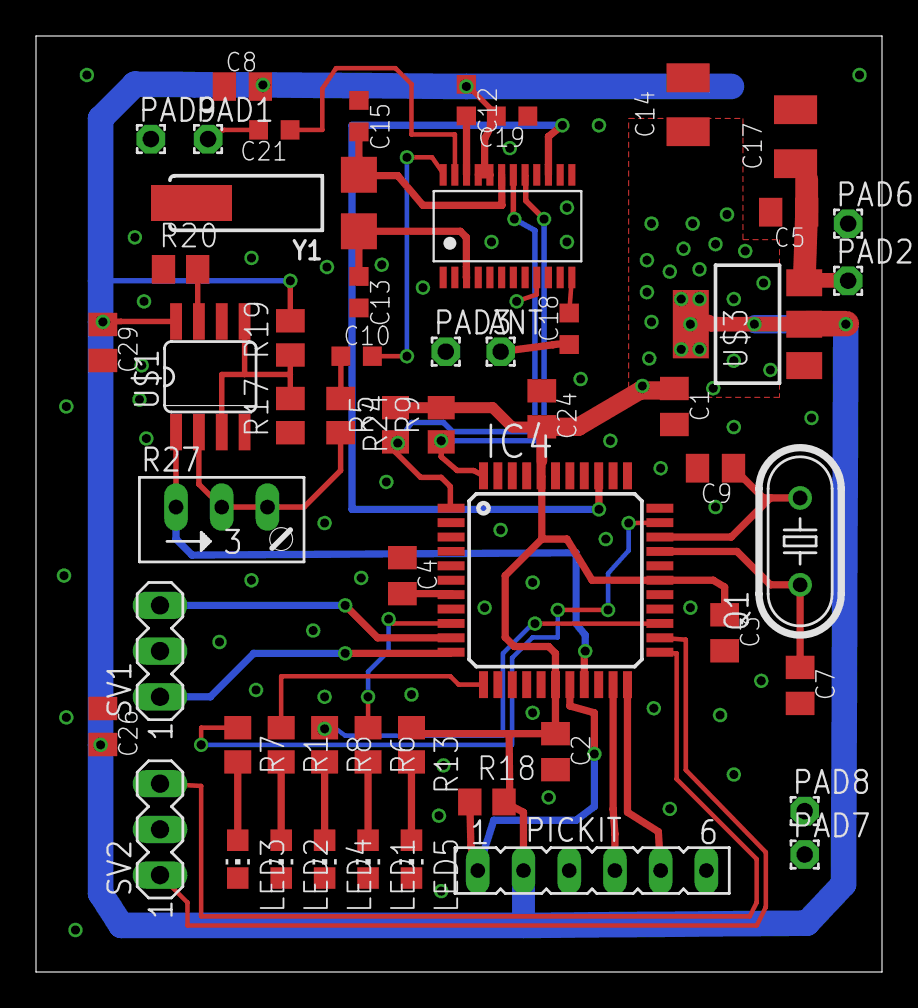
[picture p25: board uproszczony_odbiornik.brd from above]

Board: 2 copper layers, 47.0 x 52.0 mm, 55 parts (0 on the bottom side), 38 nets.

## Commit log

2024-03-26 add info to readme.md
    [uproszczony_odbiornik.brd, uproszczony_odbiornik.sch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]
2024-03-26 add KiCAD project
    [uproszczony_odbiornik.kicad_pcb, uproszczony_odbiornik.kicad_sch, uproszczony_odbiornik.step]
2024-04-06 add pcb_components.pdf
2024-06-12 fix schematics and PCB, Add R2
    [bom.csv, designators.csv, positions.csv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]
2024-06-12 change read.me
    [uproszczony_odbiornik.kicad_pcb]
2024-06-14 new version of firmware, fixed pull-up pin 23 problem
